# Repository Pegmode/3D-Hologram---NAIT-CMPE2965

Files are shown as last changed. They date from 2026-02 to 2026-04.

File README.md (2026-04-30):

# 3D Hologram Capstone Project - CMPE2965 NAIT
Capstone project for Computer Engineering Technology at the Northern Alberta Institute of Technology.<br>

by: Kaden Sparrow and [Daniel Chu](http://pegmode.github.io)<br>
course: CMPE2965-A02-1252

# Synopsis
This project is a rotating 3D volumetric display. Comprised of a rotating 16x32 LED display on a custom 6 layer circuit board with integrated microcontroller. Controlled via control UI running on windows. Able to load 3D models in the `.obj` format. 

<br>
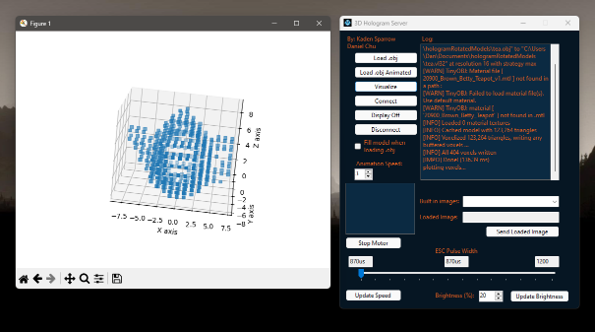
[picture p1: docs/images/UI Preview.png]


# Project History
This repo was initially worked on in a private repository created by Github classroom. As such all issues present in the original repository is not present in this one.

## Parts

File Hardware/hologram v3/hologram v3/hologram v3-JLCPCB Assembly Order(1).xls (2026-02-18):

JLCPCB BOM Tool - BOM Matching
BOM name：hologram v3-JLCPCB Assembly Order.xlsx |  |  | Download Time：2026-02-17 16:09:45 |  |  |  | * Our matching results are updated in real-time, but stock and prices may change. If it's been over 24 hours, please re-match before placing your order.
PCB Assembled Qty：5 |  |  | Est. Total Price：37.8607
Your BOM |  |  |  |  | Matched Parts |  |  |  |  |  |  | Order Information
Top Designator | Bottom Designator | Comment | Footprint | JLCPCB Part # | Matches | Part # | Manufacturer | Footprint | Description | Category | Warning | JLCPCB Part # | Product link | Lib Type | Qty | Source | Total Price ($)
 | C1,C2,C3,C4,C5,C6,C7,C8,C9,C10,C11,C12,C13,C14,C15,C16,C17,C18,C19,C20,C21,C22,C23,C24,C25,C26,C27,C28,C29,C30,C31,C32 | C_Small | Capacitor_SMD:C_0603_1608Metric |  | Select by Customer | CC0603KRX7R9BB104 | YAGEO | 0603 | 100nF 50V X7R ±10% 0603 Multilayer Ceramic Capacitors MLCC - SMD/SMT ROHS | Multilayer Ceramic Capacitors MLCC - SMD/SMT |  | C14663 | https://jlcpcb.com/partdetail/YAGEO-CC0603KRX7R9BB104/C14663 | Basic | 74 | 74 JLCPCB | 0.1924
C33 |  | 22u | Capacitor_SMD:C_1210 |  | Select by Customer | CS3225X7R226K250NRL | Samwha Capacitor | 1210 | 22uF 25V X7R ±10% 1210 Multilayer Ceramic Capacitors MLCC - SMD/SMT ROHS | Multilayer Ceramic Capacitors MLCC - SMD/SMT | 1.Multiple lines in the BOM have been matched to the same part. Please check if the matching is correct. ; | C2918511 | https://jlcpcb.com/partdetail/3220363-CS3225X7R226K250NRL/C2918511 | Extended | 26 | 26 JLCPCB | 2.262
C46,C47 | C53,C54,C61,C62,C63,C64 | 22u | Capacitor_SMD:C_1210_3225Metric |  | Select by Customer | CS3225X7R226K250NRL | Samwha Capacitor | 1210 | 22uF 25V X7R ±10% 1210 Multilayer Ceramic Capacitors MLCC - SMD/SMT ROHS | Multilayer Ceramic Capacitors MLCC - SMD/SMT | 1.The comment (CS3225X7R226K250NRL) of this part does not match the one (22u) provided in your BOM. Please confirm; 2.Multiple lines in the BOM have been matched to the same part. Please check if the matching is correct. ; | C2918511 | https://jlcpcb.com/partdetail/3220363-CS3225X7R226K250NRL/C2918511 | Extended | 26 | 26 JLCPCB | 2.262
C34,C37,C40,C42,C44 | C38,C39,C55,C56,C60 | 0.1u | Capacitor_SMD:C_0402_1005Metric |  | Select by Customer | CL05B104KB54PNC | Samsung Electro-Mechanics | 0402 | 100nF 50V X7R ±10% 0402 Multilayer Ceramic Capacitors MLCC - SMD/SMT ROHS | Multilayer Ceramic Capacitors MLCC - SMD/SMT | 1.The comment (CL05B104KB54PNC) of this part does not match the one (0.1u) provided in your BOM. Please confirm; | C307331 | https://jlcpcb.com/partdetail/291005-CL05B104KB54PNC/C307331 | Basic | 40 | 40 JLCPCB | 0.164
C35,C45 |  | 1u | Capacitor_SMD:C_0603_1608Metric |  | Select by Customer | 0603B105K250NT | FH (Guangdong Fenghua Advanced Tech) | 0603 | 1uF 25V X7R ±10% 0603 Multilayer Ceramic Capacitors MLCC - SMD/SMT ROHS | Multilayer Ceramic Capacitors MLCC - SMD/SMT | 1.The comment (0603B105K250NT) of this part does not match the one (1u) provided in your BOM. Please confirm; | C59302 | https://jlcpcb.com/partdetail/60350-0603B105K250NT/C59302 | Extended | 20 | 20 JLCPCB | 0.104
C36 |  | 10u | Capacitor_SMD:C_0805_2012Metric |  | Unconfirmed | GRM21BR61H106KE43L | Murata Electronics | 0805 | 10uF 50V X5R ±10% 0805 Multilayer Ceramic Capacitors MLCC - SMD/SMT ROHS | Multilayer Ceramic Capacitors MLCC - SMD/SMT | 1.The comment (GRM21BR61H106KE43L) of this part does not match the one (10u) provided in your BOM. Please confirm; | C440198 | https://jlcpcb.com/partdetail/439567-GRM21BR61H106KE43L/C440198 | Basic | 6 | 6 JLCPCB | 0.393
 | C48 | 100u | easyeda:CAP-SMD_BD6.3-L6.6-W6.6-LS7.3-FD |  | Select by System | MA25V100M6x6 | jieerrui | SMD,D6.3xL6mm | -55℃~+105℃ 100uF 2.65A@100kHz 2000hrs@105℃ 25V 30mΩ@100kHz 6.3mm 6mm Polymer ±20% SMD,D6.3xL6mm Polymer Aluminum Capacitors ROHS |  |  | C46550465 | https://jlcpcb.com/partdetail/jieerrui-MA25V100M6x6/C46550465 | Extended | 2 | 2 JLCPCB | 0.3258
C49,C50,C51,C52,C59,C65,C66,C67 |  | 47u | Capacitor_SMD:C_1210_3225Metric |  | Select by Customer | CS3225X7R476K160NRL | Samwha Capacitor | 1210 | 16V 47uF X7R ±10% 1210 Multilayer Ceramic Capacitors MLCC - SMD/SMT ROHS | Multilayer Ceramic Capacitors MLCC - SMD/SMT | 1.The comment (CS3225X7R476K160NRL) of this part does not match the one (47u) provided in your BOM. Please confirm; | C5440143 | https://jlcpcb.com/partdetail/6321105-CS3225X7R476K160NRL/C5440143 | Extended | 18 | 18 JLCPCB | 1.7784
C43 | C57 | 2.2u | Capacitor_SMD:C_0603_1608Metric |  | Select by Customer | GRM188Z71E225KE43D | Murata Electronics | 0603 | 2.2uF 25V X7R ±10% 0603 Multilayer Ceramic Capacitors MLCC - SMD/SMT ROHS | Multilayer Ceramic Capacitors MLCC - SMD/SMT | 1.The comment (GRM188Z71E225KE43D) of this part does not match the one (2.2u) provided in your BOM. Please confirm; | C415535 | https://jlcpcb.com/partdetail/408029-GRM188Z71E225KE43D/C415535 | Extended | 12 | 12 JLCPCB | 0.4836
D1 |  | 1N5819HW-7-F | easyeda:SOD-123_L2.7-W1.6-LS3.7-RD |  | Select by System | 1N5819HW-7-F | Diodes Incorporated | SOD-123 | -65℃~+150℃ 1 Independent 1A 1mA@40V 25A 40V 450mV@1A SOD-123 Schottky Diodes ROHS | Schottky Diodes |  | C82544 | https://jlcpcb.com/partdetail/DiodesIncorporated-1N5819HW_7F/C82544 | Extended | 15 | 15 JLCPCB | 0.4365
D2,D3,D4 |  | LESD5Z5.0CT1G | easyeda:SOD-523_L1.2-W0.8-LS1.6-BI |  | Select by System | LESD5Z5.0CT1G-HXY | HXY MOSFET | SOD-523 | -40℃~+125℃ 1 11.6V 15pF 1uA 5V 7.8V 90W@8/20us 9A Bidirectional ESD IEC 61000-4-2、IEC 61000-4-4 SOD-523 ESD and Surge Protection (TVS/ESD) ROHS | ESD And Surge Protection (TVS/ESD) |  | C5451650 | https://jlcpcb.com/partdetail/HXYMOSFET-LESD5Z5_0CT1GHXY/C5451650 | Extended | 20 | 20 JLCPCB | 0.254
 | D5,D6,D7,D8 | LESD5Z5.0CT1G | easyeda:SOD-523_L1.2-W0.8-LS1.6-BI |  | Select by System | LESD5Z5.0CT1G | LRC | SOD-523 | -40℃~+125℃ 18.6V 1uA 200W@8/20us 25pF 5V 7.8V 9.4A@8/20us Bidirectional IEC 61000-4-2、IEC 61000-4-4 TVS SOD-523 ESD and Surge Protection (TVS/ESD) ROHS | ESD And Surge Protection (TVS/ESD) |  | C136167 | https://jlcpcb.com/partdetail/LRC-LESD5Z50CT1G/C136167 | Extended | 20 | 20 JLCPCB | 0.342
 | D9 | SMBJ13A | easyeda:SMB_L4.6-W3.6-LS5.3-RD |  | Select by Customer | SMBJ13A | Littelfuse | DO-214AA | -65℃~+150℃ 14V 17.2V 1uA 23.2V 25.9A@10/1000us 600W@10/1000us IEC 61000-4-2 TVS Unidirectional DO-214AA ESD and Surge Protection (TVS/ESD) ROHS | ESD And Surge Protection (TVS/ESD) |  | C151252 | https://jlcpcb.com/partdetail/Littelfuse-SMBJ13A/C151252 | Extended | 5 | 5 JLCPCB | 0.546
 | D10 | KT-0603R | LED_SMD:LED_0603_1608Metric |  | Select by System | KT-0603R | Hubei KENTO Elec | 0603 | -40℃~+85℃ 120° 2.4V 20mA 300mcd 40mW 615nm~630nm 645nm Discrete Diode Red Water Clear 0603 LED Indication - Discrete ROHS | LED Indication - Discrete |  | C2286 | https://jlcpcb.com/partdetail/Hubei_KENTOElec-KT0603R/C2286 | Basic | 20 | 20 JLCPCB | 0.128
 | D11 | KT-0603Y | LED_SMD:LED_0603_1608Metric |  | Select by System | KT-0603Y | Hubei KENTO Elec | 0603 | -40℃~+85℃ 120° 175mcd 2.4V 40mW 584nm~594nm 596nm Discrete Diode Water Clear Yellow 0603 LED Indication - Discrete ROHS | LED Indication - Discrete |  | C2287 | https://jlcpcb.com/partdetail/Hubei_KENTOElec-KT0603Y/C2287 | Extended | 20 | 20 JLCPCB | 0.206
 | D12 | KT-0603B | LED_SMD:LED_0603_1608Metric |  | Select by System | KT-0603B | Hubei KENTO Elec | 0603 | 100mW 120° 175mcd 3.1V 460nm~475nm 469nm 5mA Blue Discrete Diode Water Clear 0603 LED Indication - Discrete ROHS | LED Indication - Discrete |  | C2288 | https://jlcpcb.com/partdetail/Hubei_KENTOElec-KT0603B/C2288 | Extended | 20 | 20 JLCPCB | 0.198
 | F1 | SMD1812-300C-30V | Fuse:Fuse_1812_4532Metric |  | Select by System | SMD1812-300C-30V | BNstar | 1812 | 10mΩ 30V 3A 4s 50A 60mΩ 6A 800mW 1812 Resettable Fuses ROHS | Resettable Fuses |  | C47002391 | https://jlcpcb.com/partdetail/BNstar-SMD1812_300C30V/C47002391 | Extended | 5 | 5 JLCPCB | 0.8335
L1 |  | 2.2u | easyeda:IND-SMD_L10.8-W10.0 |  | Select by Customer | CMLO1040H2R2MTT | Cybermax | SMD,10.8x10mm | 12A 2.2uH 5.8mΩ Magnetic Shielded Inductor ±20% SMD,10.8x10mm Power Inductors ROHS | Power Inductors | 1.The comment (CMLO1040H2R2MTT) of this part does not match the one (2.2u) provided in your BOM. Please confirm; | C439019 | https://jlcpcb.com/partdetail/Cybermax-CMLO1040H2R2MTT/C439019 | Extended | 2 | 2 JLCPCB | 0.5146
 | L2 | 4.7u | easyeda:IND-SMD_L10.8-W10.0 |  | Select by Customer | CMLO1040H4R7MTT | Cybermax | SMD,10.8x10mm | 12mΩ 4.7uH 8.5A Magnetic Shielded Inductor ±20% SMD,10.8x10mm Power Inductors ROHS | Power Inductors | 1.The comment (CMLO1040H4R7MTT) of this part does not match the one (4.7u) provided in your BOM. Please confirm; | C439021 | https://jlcpcb.com/partdetail/Cybermax-CMLO1040H4R7MTT/C439021 | Extended | 2 | 2 JLCPCB | 0.524
LED1,LED2,LED3,LED4,LED5,LED6,LED7,LED8,LED9,LED10,LED11,LED12,LED13,LED14,LED15,LED16,LED17,LED18,LED19,LED20,LED21,LED22,LED23,LED24,LED25,LED26,LED27,LED28,LED29,LED30,LED31,LED32,LED33,LED34,LED35,LED36,LED37,LED38,LED39,LED40,LED41,LED42,LED43,LED44,LED45,LED46,LED47,LED48,LED49,LED50,LED51,LED52,LED53,LED54,LED55,LED56,LED57,LED58,LED59,LED60,LED61,LED62,LED63,LED64,LED65,LED66,LED67,LED68,LED69,LED70,LED71,LED72,LED73,LED74,LED75,LED76,LED77,LED78,LED79,LED80,LED81,LED82,LED83,LED84,LED85,LED86,LED87,LED88,LED89,LED90,LED91,LED92,LED93,LED94,LED95,LED96,LED97,LED98,LED99,LED100,LED101,LED102,LED103,LED104,LED105,LED106,LED107,LED108,LED109,LED110,LED111,LED112,LED113,LED114,LED115,LED116,LED117,LED118,LED119,LED120,LED121,LED122,LED123,LED124,LED125,LED126,LED127,LED128,LED129,LED130,LED131,LED132,LED133,LED134,LED135,LED136,LED137,LED138,LED139,LED140,LED141,LED142,LED143,LED144,LED145,LED146,LED147,LED148,LED149,LED150,LED151,LED152,LED153,LED154,LED155,LED156,LED157,LED158,LED159,LED160,LED161,LED162,LED163,LED164,LED165,LED166,LED167,LED168,LED169,LED170,LED171,LED172,LED173,LED174,LED175,LED176,LED177,LED178,LED179,LED180,LED181,LED182,LED183,LED184,LED185,LED186,LED187,LED188,LED189,LED190,LED191,LED192,LED193,LED194,LED195,LED196,LED197,LED198,LED199,LED200,LED201,LED202,LED203,LED204,LED205,LED206,LED207,LED208,LED209,LED210,LED211,LED212,LED213,LED214,LED215,LED216,LED217,LED218 |  | 0805G(Green) | easyeda:LED0805-RD-flipped |  | Select by System | KT-0805G | Hubei KENTO Elec | 0805 | -40℃~+85℃ 100mW 120° 2.6V~3.1V 430mcd 513nm~528nm 525nm 5mA Discrete Diode Emerald Green Water Clear 0805 LED Indication - Discrete ROHS | LED Indication - Discrete |  | C2297 | https://jlcpcb.com/partdetail/Hubei_KENTOElec-KT0805G/C2297 | Basic | 0 | 0 JLCPCB | 0
LED219,LED220,LED221,LED222,LED223,LED224,LED225,LED226,LED227,LED228,LED229,LED230,LED231,LED232,LED233,LED234,LED235,LED236,LED237,LED238,LED239,LED240,LED241,LED242,LED243,LED244,LED245,LED246,LED247,LED248,LED249,LED250,LED251,LED252,LED253,LED254,LED255,LED256,LED257,LED258,LED259,LED260,LED261,LED262,LED263,LED264,LED265,LED266,LED267,LED268,LED269,LED270,LED271,LED272,LED273,LED274,LED275,LED276,LED277,LED278,LED279,LED280,LED281,LED282,LED283,LED284,LED285,LED286,LED287,LED288,LED289,LED290,LED291,LED292,LED293,LED294,LED295,LED296,LED297,LED298,LED299,LED300,LED301,LED302,LED303,LED304,LED305,LED306,LED307,LED308,LED309,LED310,LED311,LED312,LED313,LED314,LED315,LED316,LED317,LED318,LED319,LED320,LED321,LED322,LED323,LED324,LED325,LED326,LED327,LED328,LED329,LED330,LED331,LED332,LED333,LED334,LED335,LED336,LED337,LED338,LED339,LED340,LED341,LED342,LED343 |  | 0805G(Green) | easyeda:LED0805-RD-flipped |  | Select by System | KT-0805G | Hubei KENTO Elec | 0805 | -40℃~+85℃ 100mW 120° 2.6V~3.1V 430mcd 513nm~528nm 525nm 5mA Discrete Diode Emerald Green Water Clear 0805 LED Indication - Discrete ROHS | LED Indication - Discrete |  | C2297 | https://jlcpcb.com/partdetail/Hubei_KENTOElec-KT0805G/C2297 | Basic | 0 | 0 JLCPCB | 0
LED344,LED345,LED346,LED347,LED348,LED349,LED350,LED351,LED352,LED353,LED354,LED355,LED356,LED357,LED358,LED359,LED360,LED361,LED362,LED363,LED364,LED365,LED366,LED367,LED368,LED369,LED370,LED371,LED372,LED373,LED374,LED375,LED376,LED377,LED378,LED379,LED380,LED381,LED382,LED383,LED384,LED385,LED386,LED387,LED388,LED389,LED390,LED391,LED392,LED393,LED394,LED395,LED396,LED397,LED398,LED399,LED400,LED401,LED402,LED403,LED404,LED405,LED406,LED407,LED408,LED409,LED410,LED411,LED412,LED413,LED414,LED415,LED416,LED417,LED418,LED419,LED420,LED421,LED422,LED423,LED424,LED425,LED426,LED427,LED428,LED429,LED430,LED431,LED432,LED433,LED434,LED435,LED436,LED437,LED438,LED439,LED440,LED441,LED442,LED443,LED444,LED445,LED446,LED447,LED448,LED449,LED450,LED451,LED452,LED453,LED454,LED455,LED456,LED457,LED458,LED459,LED460,LED461,LED462,LED463,LED464,LED465,LED466,LED467,LED468,LED469,LED470,LED471,LED472,LED473,LED474,LED475,LED476,LED477,LED478,LED479,LED480,LED481,LED482,LED483,LED484,LED485,LED486,LED487,LED488,LED489,LED490,LED491,LED492,LED493,LED494,LED495,LED496,LED497,LED498,LED499,LED500,LED501,LED502,LED503,LED504,LED505,LED506,LED507,LED508,LED509,LED510,LED511,LED512 |  | 0805G(Green) | easyeda:LED0805-RD-flipped |  | Select by System | KT-0805G | Hubei KENTO Elec | 0805 | -40℃~+85℃ 100mW 120° 2.6V~3.1V 430mcd 513nm~528nm 525nm 5mA Discrete Diode Emerald Green Water Clear 0805 LED Indication - Discrete ROHS | LED Indication - Discrete |  | C2297 | https://jlcpcb.com/partdetail/Hubei_KENTOElec-KT0805G/C2297 | Basic | 0 | 0 JLCPCB | 0
 | R1 | 1.65k0.25% | Resistor_SMD:R_0603_1608Metric |  | Select by Customer | RT0603CRE071K65L | YAGEO | 0603 | -55℃~+155℃ 1.65kΩ 100mW 75V Thin Film Resistor ±0.25% ±50ppm/℃ 0603 Chip Resistor - Surface Mount ROHS | Chip Resistor - Surface Mount | 1.The comment (RT0603CRE071K65L) of this part does not match the one (1.65k0.25%) provided in your BOM. Please confirm; 2.Multiple lines in the BOM have been matched to the same part. Please check if the matching is correct. ; | C705912 | https://jlcpcb.com/partdetail/YAGEO-RT0603CRE071K65L/C705912 | Extended | 74 | 74 JLCPCB | 1.48
 | R2,R3,R4,R5,R6,R7,R8,R9,R10,R11,R12,R13,R14,R15,R16,R17,R18,R19,R20,R21,R22,R23,R24,R25,R26,R27,R28,R29,R30,R31,R32 | R_US | Resistor_SMD:R_0603_1608Metric |  | Select by Customer | RT0603CRE071K65L | YAGEO | 0603 | -55℃~+155℃ 1.65kΩ 100mW 75V Thin Film Resistor ±0.25% ±50ppm/℃ 0603 Chip Resistor - Surface Mount ROHS | Chip Resistor - Surface Mount | 1.Multiple lines in the BOM have been matched to the same part. Please check if the matching is correct. ; | C705912 | https://jlcpcb.com/partdetail/YAGEO-RT0603CRE071K65L/C705912 | Extended | 74 | 74 JLCPCB | 1.48
R33 |  | 1M | Resistor_SMD:R_0603_1608Metric |  | Unconfirmed | 0603WAF1004T5E | UNI-ROYAL(Uniroyal Elec) | 0603 | -55℃~+155℃ 100mW 1MΩ 75V Thick Film Resistor ±1% ±100ppm/℃ 0603 Chip Resistor - Surface Mount ROHS | Chip Resistor - Surface Mount | 1.The comment (0603WAF1004T5E) of this part does not match the one (1M) provided in your BOM. Please confirm; | C22935 | https://jlcpcb.com/partdetail/23662-0603WAF1004T5E/C22935 | Basic | 20 | 20 JLCPCB | 0.022
R34,R41,R47 | R62 | 10k | Resistor_SMD:R_0603_1608Metric |  | Select by Customer | FRH0603B1002TS | FOJAN | 0603 | -55℃~+155℃ 100mW 10kΩ 75V Thick Film Resistor ±0.1% ±100ppm/℃ 0603 Chip Resistor - Surface Mount ROHS | Chip Resistor - Surface Mount | 1.The comment (FRH0603B1002TS) of this part does not match the one (10k) provided in your BOM. Please confirm; | C5126214 | https://jlcpcb.com/partdetail/FOJAN-FRH0603B1002TS/C5126214 | Extended | 40 | 40 JLCPCB | 0.26
R35,R36 |  | 5.11k | Resistor_SMD:R_0603_1608Metric |  | Select by Customer | 0603WAF5101T5E | UNI-ROYAL(Uniroyal Elec) | 0603 | -55℃~+155℃ 100mW 5.1kΩ 75V Thick Film Resistor ±1% ±100ppm/℃ 0603 Chip Resistor - Surface Mount ROHS | Chip Resistor - Surface Mount | 1.The comment (0603WAF5101T5E) of this part does not match the one (5.11k) provided in your BOM. Please confirm; | C23186 | https://jlcpcb.com/partdetail/23913-0603WAF5101T5E/C23186 | Basic | 20 | 20 JLCPCB | 0.024
 | R37,R38,R39 | 2.2k | Resistor_SMD:R_0603_1608Metric |  | Select by Customer | 0603WAF2201T5E | UNI-ROYAL(Uniroyal Elec) | 0603 | -55℃~+155℃ 100mW 2.2kΩ 75V Thick Film Resistor ±1% ±100ppm/℃ 0603 Chip Resistor - Surface Mount ROHS | Chip Resistor - Surface Mount | 1.The comment (0603WAF2201T5E) of this part does not match the one (2.2k) provided in your BOM. Please confirm; | C4190 | https://jlcpcb.com/partdetail/4597-0603WAF2201T5E/C4190 | Basic | 20 | 20 JLCPCB | 0.026
R42,R43,R44,R45,R46,R49,R50,R55,R65,R66 |  | 33 | Resistor_SMD:R_0402_1005Metric |  | Select by Customer | 0603WAF330JT5E | UNI-ROYAL(Uniroyal Elec) | 0603 | -55℃~+155℃ 100mW 33Ω 75V Thick Film Resistor ±1% ±100ppm/℃ 0603 Chip Resistor - Surface Mount ROHS | Chip Resistor - Surface Mount | 1.The comment (0603WAF330JT5E) of this part does not match the one (33) provided in your BOM. Please confirm; | C23140 | https://jlcpcb.com/partdetail/23867-0603WAF330JT5E/C23140 | Basic | 30 | 30 JLCPCB | 0.036
R48 |  | 75k | Resistor_SMD:R_0603_1608Metric |  | Select by Customer | RT0603BRD0775KL | YAGEO | 0603 | -55℃~+155℃ 100mW 75V 75kΩ Thin Film Resistor ±0.1% ±25ppm/℃ 0603 Chip Resistor - Surface Mount ROHS | Chip Resistor - Surface Mount | 1.The comment (RT0603BRD0775KL) of this part does not match the one (75k) provided in your BOM. Please confirm; | C723587 | https://jlcpcb.com/partdetail/YAGEO-RT0603BRD0775KL/C723587 | Extended | 20 | 20 JLCPCB | 0.536
R51 |  | 13k | Resistor_SMD:R_0603_1608Metric |  | Select by Customer | TC0325B1302T5F | UNI-ROYAL(Uniroyal Elec) | 0603 | -55℃~+155℃ 100mW 13kΩ Thin Film Resistor ±0.1% ±25ppm/℃ 0603 Chip Resistor - Surface Mount ROHS |  | 1.The comment (TC0325B1302T5F) of this part does not match the one (13k) provided in your BOM. Please confirm; | C50670543 | https://jlcpcb.com/partdetail/53304658-TC0325B1302T5F/C50670543 | Extended | 2 | 2 JLCPCB | 0.0212
R52,R53 | R40,R58 | 100k | Resistor_SMD:R_0603_1608Metric |  | Select by Customer | 0603WAF1003T5E | UNI-ROYAL(Uniroyal Elec) | 0603 | -55℃~+155℃ 100kΩ 100mW 75V Thick Film Resistor ±1% ±100ppm/℃ 0603 Chip Resistor - Surface Mount ROHS | Chip Resistor - Surface Mount | 1.The comment (0603WAF1003T5E) of this part does not match the one (100k) provided in your BOM. Please confirm; | C25803 | https://jlcpcb.com/partdetail/26546-0603WAF1003T5E/C25803 | Basic | 40 | 40 JLCPCB | 0.044
 | R57 | 1.5k | Resistor_SMD:R_0603_1608Metric |  | Select by System | 0603WAF1501T5E | UNI-ROYAL(Uniroyal Elec) | 0603 | -55℃~+155℃ 1.5kΩ 100mW 75V Thick Film Resistor ±1% ±100ppm/℃ 0603 Chip Resistor - Surface Mount ROHS | Chip Resistor - Surface Mount |  | C22843 | https://jlcpcb.com/partdetail/23570-0603WAF1501T5E/C22843 | Basic | 20 | 20 JLCPCB | 0.024
 | R59 | 1.2k | Resistor_SMD:R_0603_1608Metric |  | Select by System | 0603WAF1201T5E | UNI-ROYAL(Uniroyal Elec) | 0603 | -55℃~+155℃ 1.2kΩ 100mW 75V Thick Film Resistor ±1% ±100ppm/℃ 0603 Chip Resistor - Surface Mount ROHS | Chip Resistor - Surface Mount |  | C22765 | https://jlcpcb.com/partdetail/23492-0603WAF1201T5E/C22765 | Basic | 20 | 20 JLCPCB | 0.026
 | R60 | 330 | Resistor_SMD:R_0603_1608Metric |  | Select by System | 0603WAF3300T5E | UNI-ROYAL(Uniroyal Elec) | 0603 | -55℃~+155℃ 100mW 330Ω 75V Thick Film Resistor ±1% ±100ppm/℃ 0603 Chip Resistor - Surface Mount ROHS | Chip Resistor - Surface Mount |  | C23138 | https://jlcpcb.com/partdetail/23865-0603WAF3300T5E/C23138 | Basic | 20 | 20 JLCPCB | 0.026
R54 | R63,R64 | 47k | Resistor_SMD:R_0603_1608Metric |  | Unconfirmed | 0603WAF4702T5E | UNI-ROYAL(Uniroyal Elec) | 0603 | -55℃~+155℃ 100mW 47kΩ 75V Thick Film Resistor ±1% ±100ppm/℃ 0603 Chip Resistor - Surface Mount ROHS | Chip Resistor - Surface Mount | 1.The comment (0603WAF4702T5E) of this part does not match the one (47k) provided in your BOM. Please confirm; | C25819 | https://jlcpcb.com/partdetail/26562-0603WAF4702T5E/C25819 | Basic | 40 | 40 JLCPCB | 0.048
 | SW1 | SW_Reset | easyeda:KEY-SMD_L4.0-W3.0-LS4.9-1 |  | Select by Customer | HX 3x4x2-2P-1.6N TACTILE SWITCH | hanxia | SMD,4x3mm | 1.6N 100,000 cycles 12V 2mm 3mm 4mm 50mA Black No Round Button SMD(SMT) Tab SPST Surface Mount,Vertical Without Bracket SMD,4x3mm Tactile Switches ROHS |  | 1.Multiple lines in the BOM have been matched to the same part. Please check if the matching is correct. ; | C49234124 | https://jlcpcb.com/partdetail/C49234124 | Extended | 10 | 10 JLCPCB | 0.2
 | SW2 | SW_Boot | easyeda:KEY-SMD_L4.0-W3.0-LS4.9-1 |  | Select by Customer | HX 3x4x2-2P-1.6N TACTILE SWITCH | hanxia | SMD,4x3mm | 1.6N 100,000 cycles 12V 2mm 3mm 4mm 50mA Black No Round Button SMD(SMT) Tab SPST Surface Mount,Vertical Without Bracket SMD,4x3mm Tactile Switches ROHS |  | 1.Multiple lines in the BOM have been matched to the same part. Please check if the matching is correct. ; | C49234124 | https://jlcpcb.com/partdetail/C49234124 | Extended | 10 | 10 JLCPCB | 0.2
 | SW3 | SW_OPT1 | easyeda:KEY-SMD_L4.0-W3.0-LS4.9-1 |  | Select by Customer | HX 3x4x2-2P-1.6N TACTILE SWITCH | hanxia | SMD,4x3mm | 1.6N 100,000 cycles 12V 2mm 3mm 4mm 50mA Black No Round Button SMD(SMT) Tab SPST Surface Mount,Vertical Without Bracket SMD,4x3mm Tactile Switches ROHS |  | 1.Multiple lines in the BOM have been matched to the same part. Please check if the matching is correct. ; | C49234124 | https://jlcpcb.com/partdetail/C49234124 | Extended | 10 | 10 JLCPCB | 0.2
 | SW4 | SW_OPT2 | easyeda:KEY-SMD_L4.0-W3.0-LS4.9-1 |  | Select by Customer | HX 3x4x2-2P-1.6N TACTILE SWITCH | hanxia | SMD,4x3mm | 1.6N 100,000 cycles 12V 2mm 3mm 4mm 50mA Black No Round Button SMD(SMT) Tab SPST Surface Mount,Vertical Without Bracket SMD,4x3mm Tactile Switches ROHS |  | 1.Multiple lines in the BOM have been matched to the same part. Please check if the matching is correct. ; | C49234124 | https://jlcpcb.com/partdetail/C49234124 | Extended | 10 | 10 JLCPCB | 0.2
 | U1,U2,U3,U4,U5,U6,U7,U8,U9,U10,U11,U12,U13,U14,U15,U16,U17,U18,U19,U20,U21,U22,U23,U24,U25,U26,U27,U28,U29,U30,U31,U32 | SM16106SC | easyeda:QSOP-24_L8.7-W4.0-P0.64-LS6.0-BL |  | Select by System | SM16206S | Shenzhen Sunmoon Micro | QSOP-24 | -40℃~+85℃ 16 2.5% 25MHz 3.3V~5V 32mA QSOP-24 LED Drivers ROHS | LED Drivers |  | C121618 | https://jlcpcb.com/partdetail/Shenzhen_SunmoonMicro-SM16206S/C121618 | Extended | 64 | 64 JLCPCB | 4.7936
U33 |  | ESP32-S3-WROOM-1(N16R8) | easyeda:WIRELM-SMD_ESP32-S3-WROOM-1 |  | Select by System | ESP32-S3-WROOM-1-N16R8 | Espressif Systems | SMD,25.5x18mm | -103.5dBm -40℃~+65℃ 2.4GHz 20.5dBm 355mA 3V~3.6V 95mA ESP32-S3R8 On-board PCB Antenna UART、SPI、I2C、GPIO、I2S、USB SMD,25.5x18mm WiFi Modules ROHS | WiFi Modules |  | C2913202 | https://jlcpcb.com/partdetail/3198300-ESP32_S3_WROOM_1N16R8/C2913202 | Extended | 2 | 2 JLCPCB | 11.3824
U34 |  | SY8286ARAC12v->4v | easyeda:QFN-20_L3.0-W3.0-P0.45-BL-EP1.0 |  | Unconfirmed | SY8286ARAC | Silergy Corp | QFN-20-EP(3x3) | -40℃~+85℃@(TA) 1 120uA 4V~23V 510kHz~690kHz 6A Adjustable Buck Buck Built-in Yes QFN-20-EP(3x3) DC-DC Converters ROHS | DC-DC Converters | 1.Multiple lines in the BOM have been matched to the same part. Please check if the matching is correct. ; | C178251 | https://jlcpcb.com/partdetail/SilergyCorp-SY8286ARAC/C178251 | Extended | 4 | 4 JLCPCB | 2.3448
 | U36 | SY8286ARAC12v->3.3v | easyeda:QFN-20_L3.0-W3.0-P0.45-BL-EP1.0 |  | Unconfirmed | SY8286ARAC | Silergy Corp | QFN-20-EP(3x3) | -40℃~+85℃@(TA) 1 120uA 4V~23V 510kHz~690kHz 6A Adjustable Buck Buck Built-in Yes QFN-20-EP(3x3) DC-DC Converters ROHS | DC-DC Converters | 1.Multiple lines in the BOM have been matched to the same part. Please check if the matching is correct. ; | C178251 | https://jlcpcb.com/partdetail/SilergyCorp-SY8286ARAC/C178251 | Extended | 4 | 4 JLCPCB | 2.3448
U35 |  | ~ | easyeda:USB-C-SMD_TYPE-C-6PIN-2MD-073 |  | Select by System | TYPE-C 16PIN 2MD(073) | SHOU HAN | SMD | -25℃~+85℃ 1 16P 3A 5,000 times 5V Black Female Surface Mount, Right Angle Type-C SMD USB Connectors ROHS | USB Connectors |  | C2765186 | https://jlcpcb.com/partdetail/SHOUHAN-TYPE_C_16PIN_2MD_073/C2765186 | Extended | 3 | 3 JLCPCB | 0.1941
 | R61 | 45k | Resistor_SMD:R_0603_1608Metric |  | Unconfirmed | CR164502F | Meritek | 0603 | -55℃~+155℃ 100mW 45kΩ Thick Film Resistor ±1% ±100ppm/℃ 0603 Chip Resistor - Surface Mount ROHS | Chip Resistor - Surface Mount | 1.The comment (CR164502F) of this part does not match the one (45k) provided in your BOM. Please confirm; | C4013975 | https://jlcpcb.com/partdetail/Meritek-CR164502F/C4013975 | Extended | 20 | 0 JLCPCB | 0
J1 |  | Conn_01x06 | Connector_PinHeader_2.54mm:PinHeader_1x06_P2.54mm_Vertical |  | No matches | No Part Selected
 | J2 | Conn_01x06_Socket | TerminalBlock:TerminalBlock_MaiXu_MX126-5.0-06P_1x06_P5.00mm |  | No matches | No Part Selected
TP1 |  | TEST_USB5V | TestPoint:TestPoint_Pad_3.0x3.0mm |  | No matches | No Part Selected
 |  |  |  |  |  |  |  |  |  |  |  |  |  |  |  |  |  | top | bottom | comment | footprint | part detail | qty | source | lib | cost
 |  |  |  |  |  |  |  |  |  |  |  |  |  |  |  |  |  |  | C1,C2,C3,C4,C5,C6,C7,C8,C9,C10,C11,C12,C13,C14,C15,C16,C17,C18,C19,C20,C21,C22,C23,C24,C25,C26,C27,C28,C29,C30,C31,C32 | C_Small | Capacitor_SMD:C_0603_1608Metric | CC0603KRX7R9BB104 | 74 | JLCPCB | Basic | C$0.2614
 |  |  |  |  |  |  |  |  |  |  |  |  |  |  |  |  |  |  |  |  |  | C14663
 |  |  |  |  |  |  |  |  |  |  |  |  |  |  |  |  |  |  |  |  |  | 100nF 50V X7R ±10% 0603 Multilayer Ceramic Capacitors MLCC - SMD/SMT ROHS
 |  |  |  |  |  |  |  |  |  |  |  |  |  |  |  |  |  | C33 |  | 22u | Capacitor_SMD:C_0805_2012Metric | CL21A226MAQNNNE | 20 | JLCPCB | Basic | C$0.7174
 |  |  |  |  |  |  |  |  |  |  |  |  |  |  |  |  |  |  |  |  |  | C45783
 |  |  |  |  |  |  |  |  |  |  |  |  |  |  |  |  |  |  |  |  |  | 22uF 25V X5R ±20% 0805 Multilayer Ceramic Capacitors MLCC - SMD/SMT ROHS
 |  |  |  |  |  |  |  |  |  |  |  |  |  |  |  |  |  | C34,C37,C40,C42,C44 | C38,C39,C55,C56,C60 | 0.1u | Capacitor_SMD:C_0402_1005Metric | CL05B104KB54PNC | 40 | JLCPCB | Basic | C$0.2228
 |  |  |  |  |  |  |  |  |  |  |  |  |  |  |  |  |  |  |  |  |  | C307331
 |  |  |  |  |  |  |  |  |  |  |  |  |  |  |  |  |  |  |  |  |  | 100nF 50V X7R ±10% 0402 Multilayer Ceramic Capacitors MLCC - SMD/SMT ROHS
 |  |  |  |  |  |  |  |  |  |  |  |  |  |  |  |  |  | C35,C45 |  | 1u | Capacitor_SMD:C_0603_1608Metric | 0603B105K250NT | 20 | JLCPCB | Extended | C$0.1413
 |  |  |  |  |  |  |  |  |  |  |  |  |  |  |  |  |  |  |  |  |  | C59302
 |  |  |  |  |  |  |  |  |  |  |  |  |  |  |  |  |  |  |  |  |  | 1uF 25V X7R ±10% 0603 Multilayer Ceramic Capacitors MLCC - SMD/SMT ROHS
 |  |  |  |  |  |  |  |  |  |  |  |  |  |  |  |  |  | C36 |  | 10u | Capacitor_SMD:C_0805_2012Metric | GRM21BR61H106KE43L | 6 | JLCPCB | Basic | C$0.5340
 |  |  |  |  |  |  |  |  |  |  |  |  |  |  |  |  |  |  |  |  |  | C440198
 |  |  |  |  |  |  |  |  |  |  |  |  |  |  |  |  |  |  |  |  |  | 10uF 50V X5R ±10% 0805 Multilayer Ceramic Capacitors MLCC - SMD/SMT ROHS
 |  |  |  |  |  |  |  |  |  |  |  |  |  |  |  |  |  | C46,C47 | C53,C54,C61,C62,C63,C64 | 22u | Capacitor_SMD:C_1210_3225Metric | CS3225X7R226K250NRL | 24 | JLCPCB | Extended | C$2.8370
 |  |  |  |  |  |  |  |  |  |  |  |  |  |  |  |  |  |  |  |  |  | C2918511
 |  |  |  |  |  |  |  |  |  |  |  |  |  |  |  |  |  |  |  |  |  | 22uF 25V X7R ±10% 1210 Multilayer Ceramic Capacitors MLCC - SMD/SMT ROHS
 |  |  |  |  |  |  |  |  |  |  |  |  |  |  |  |  |  |  | C48 | 100u | easyeda:CAP-SMD_BD6.3-L6.6-W6.6-LS7.3-FD | MA25V100M6x6 | 2 | JLCPCB | Extended | C$0.4427
 |  |  |  |  |  |  |  |  |  |  |  |  |  |  |  |  |  |  |  |  |  | C46550465
 |  |  |  |  |  |  |  |  |  |  |  |  |  |  |  |  |  |  |  |  |  | -55℃~+105℃ 100uF 2.65A@100kHz 2000hrs@105℃ 25V 30mΩ@100kHz 6.3mm 6mm Polymer ±20% SMD,D6.3xL6mm Polymer Aluminum Capacitors ROHS
 |  |  |  |  |  |  |  |  |  |  |  |  |  |  |  |  |  | C49,C50,C51,C52,C59,C65,C66,C67 |  | 47u | Capacitor_SMD:C_1210_3225Metric | CS3225X7R476K160NRL | 18 | JLCPCB | Extended | C$2.4163
 |  |  |  |  |  |  |  |  |  |  |  |  |  |  |  |  |  |  |  |  |  | C5440143
 |  |  |  |  |  |  |  |  |  |  |  |  |  |  |  |  |  |  |  |  |  | 16V 47uF X7R ±10% 1210 Multilayer Ceramic Capacitors MLCC - SMD/SMT ROHS
 |  |  |  |  |  |  |  |  |  |  |  |  |  |  |  |  |  | C43 | C57 | 2.2u | Capacitor_SMD:C_0603_1608Metric | GRM188Z71E225KE43D | 12 | JLCPCB | Extended | C$0.6571
 |  |  |  |  |  |  |  |  |  |  |  |  |  |  |  |  |  |  |  |  |  | C415535
 |  |  |  |  |  |  |  |  |  |  |  |  |  |  |  |  |  |  |  |  |  | 2.2uF 25V X7R ±10% 0603 Multilayer Ceramic Capacitors MLCC - SMD/SMT ROHS
 |  |  |  |  |  |  |  |  |  |  |  |  |  |  |  |  |  | D1 |  | 1N5819HW-7-F | easyeda:SOD-123_L2.7-W1.6-LS3.7-RD | 1N5819HW-7-F | 15 | JLCPCB | Extended | C$0.5931
 |  |  |  |  |  |  |  |  |  |  |  |  |  |  |  |  |  |  |  |  |  | C82544
 |  |  |  |  |  |  |  |  |  |  |  |  |  |  |  |  |  |  |  |  |  | -65℃~+150℃ 1 Independent 1A 1mA@40V 25A 40V 450mV@1A SOD-123 Schottky Diodes ROHS
 |  |  |  |  |  |  |  |  |  |  |  |  |  |  |  |  |  | D2,D3,D4 |  | LESD5Z5.0CT1G | easyeda:SOD-523_L1.2-W0.8-LS1.6-BI | LESD5Z5.0CT1G-HXY | 20 | JLCPCB | Extended | C$0.3451
 |  |  |  |  |  |  |  |  |  |  |  |  |  |  |  |  |  |  |  |  |  | C5451650
 |  |  |  |  |  |  |  |  |  |  |  |  |  |  |  |  |  |  |  |  |  | -40℃~+125℃ 1 11.6V 15pF 1uA 5V 7.8V 90W@8/20us 9A Bidirectional ESD IEC 61000-4-2、IEC 61000-4-4 SOD-523 ESD and Surge Protection (TVS/ESD) ROHS
 |  |  |  |  |  |  |  |  |  |  |  |  |  |  |  |  |  |  | D5,D6,D7,D8 | LESD5Z5.0CT1G | easyeda:SOD-523_L1.2-W0.8-LS1.6-BI | LESD5Z5.0CT1G | 20 | JLCPCB | Extended | C$0.4647
 |  |  |  |  |  |  |  |  |  |  |  |  |  |  |  |  |  |  |  |  |  | C136167
 |  |  |  |  |  |  |  |  |  |  |  |  |  |  |  |  |  |  |  |  |  | -40℃~+125℃ 18.6V 1uA 200W@8/20us 25pF 5V 7.8V 9.4A@8/20us Bidirectional IEC 61000-4-2、IEC 61000-4-4 TVS SOD-523 ESD and Surge Protection (TVS/ESD) ROHS
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

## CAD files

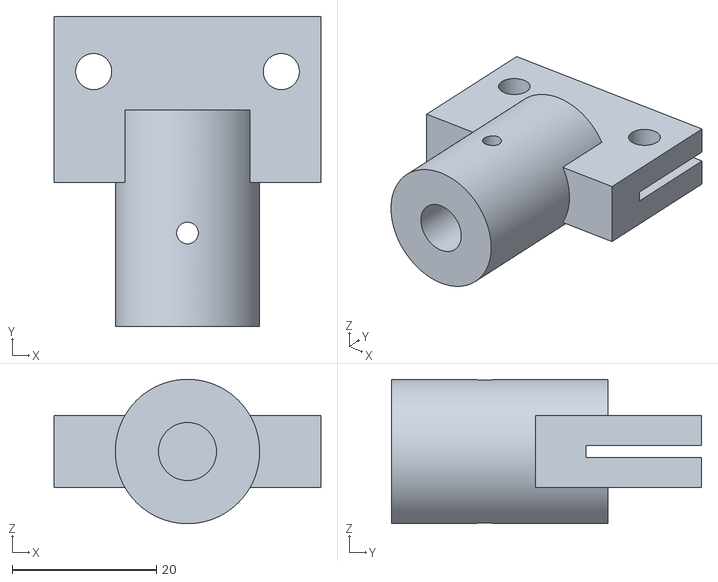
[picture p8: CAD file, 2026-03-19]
Hardware/Mechanical Parts/Board Connector Bottom/BoardConnectorBottom V5.stl
37.0 x 43.0 x 20.0

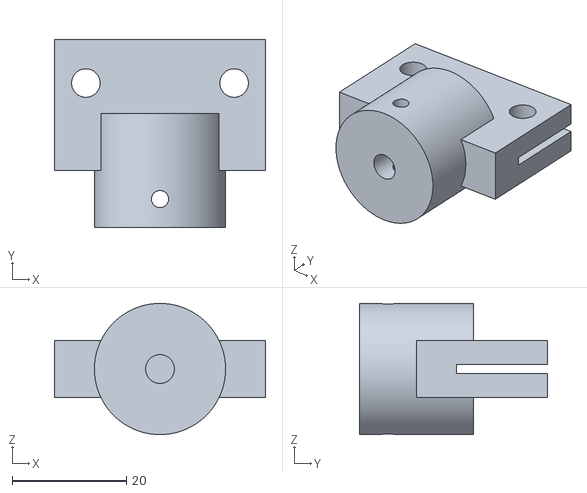
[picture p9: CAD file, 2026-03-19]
Hardware/Mechanical Parts/Board Connector Top/BoardConnectorTop V2.stl
37.0 x 33.0 x 23.0

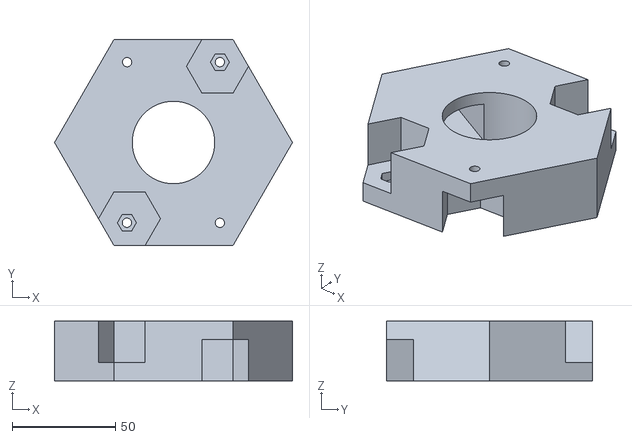
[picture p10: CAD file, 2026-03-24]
Hardware/Mechanical Parts/Motor Coupler Spacer/Motor Coupler Spacer V4.stl
115.5 x 100.0 x 29.0

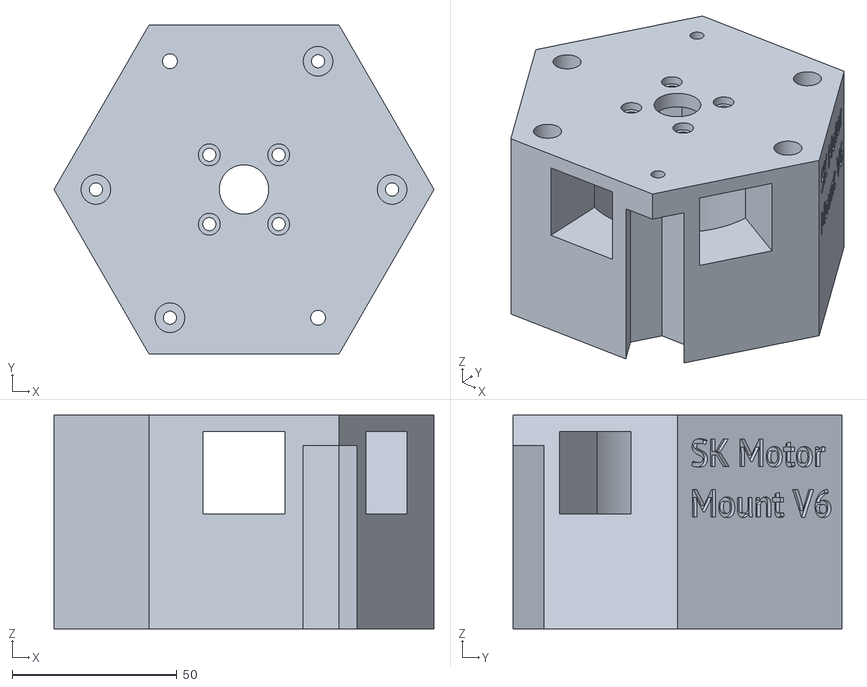
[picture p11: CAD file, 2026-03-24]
Hardware/Mechanical Parts/Motor Mount/SK Motor Mount V6.stl
115.5 x 100.0 x 65.0

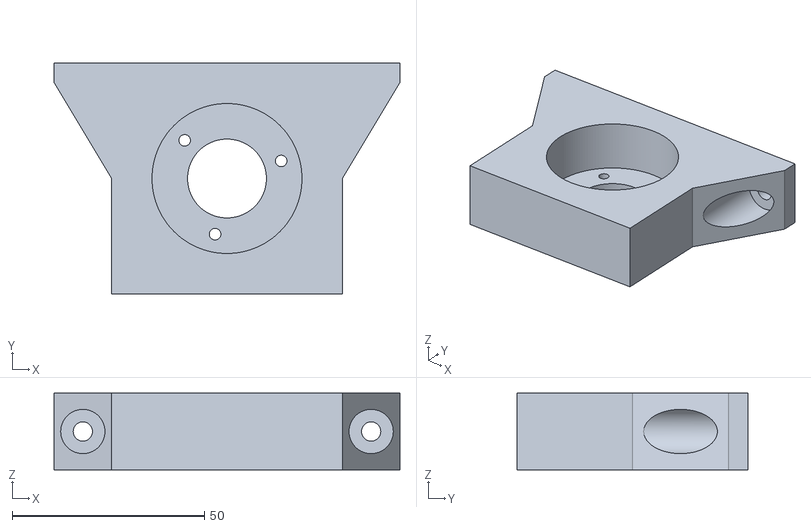
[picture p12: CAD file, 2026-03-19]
Hardware/Mechanical Parts/Rotary Encoder Mount/Rotary Encoder Mount V3.stl
90.0 x 60.0 x 20.0

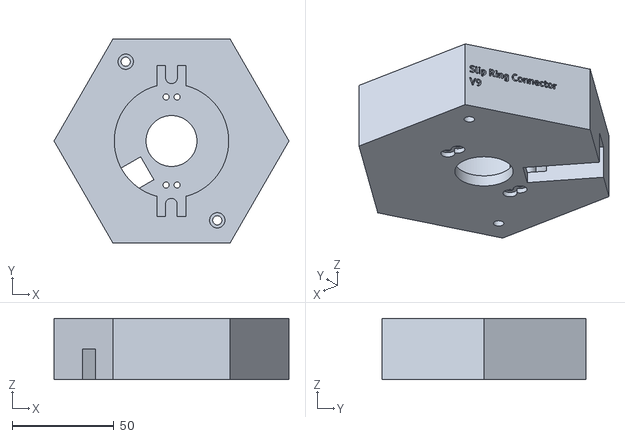
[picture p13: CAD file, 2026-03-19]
Hardware/Mechanical Parts/Slip Ring Connector/Slip Ring Connector V9.stl
115.5 x 100.0 x 30.0

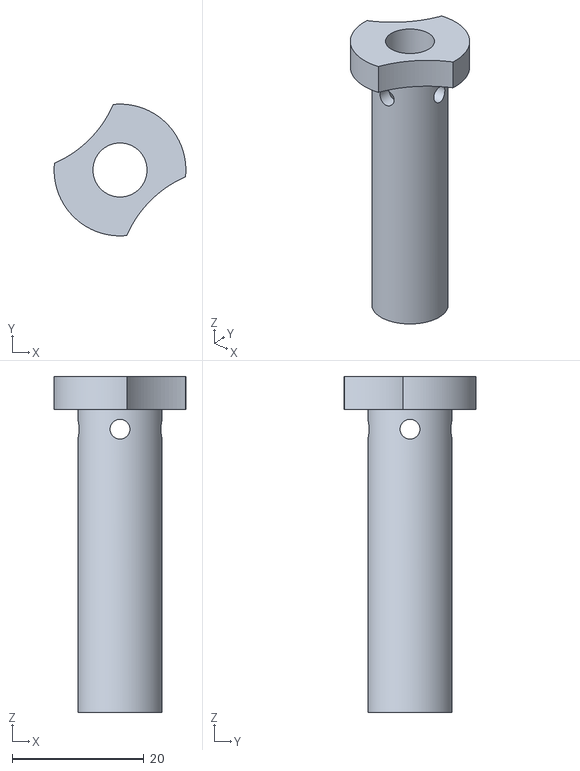
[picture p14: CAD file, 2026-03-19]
Hardware/Mechanical Parts/Slip Ring Shaft Adapter/Slip Ring Shaft Adapter V4.stl
20.0 x 20.0 x 51.0

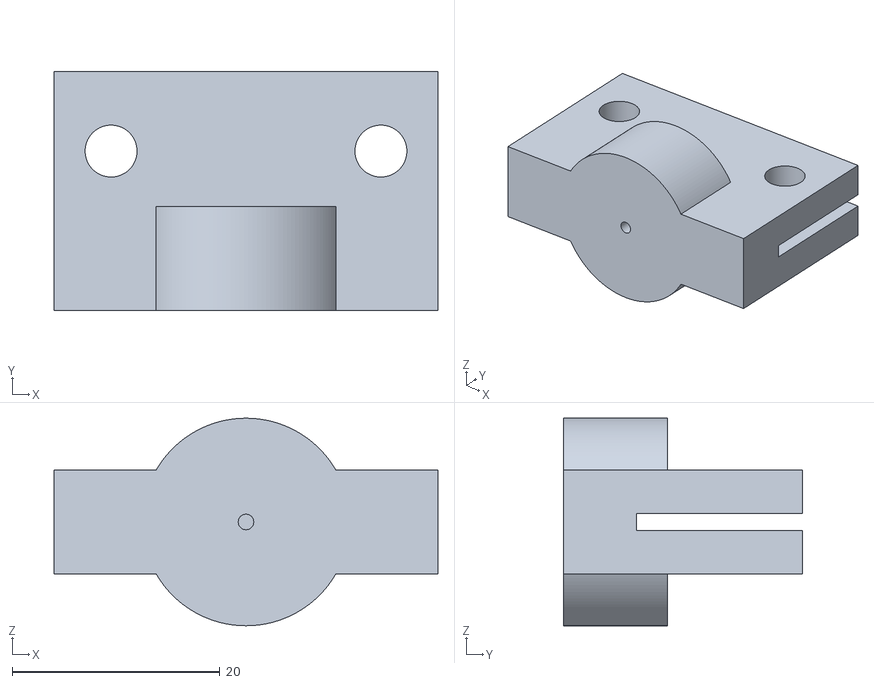
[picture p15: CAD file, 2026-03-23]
Hardware/Mechanical Parts/Test Parts/BoardConnectorBallancer V2.stl
37.0 x 23.0 x 20.0

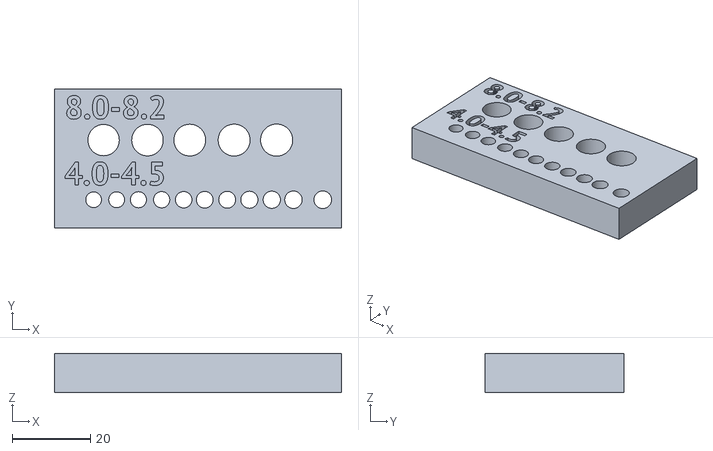
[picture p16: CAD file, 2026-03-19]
Hardware/Mechanical Parts/Test Parts/Fit Sizing Tester.stl
73.3 x 35.4 x 10.0

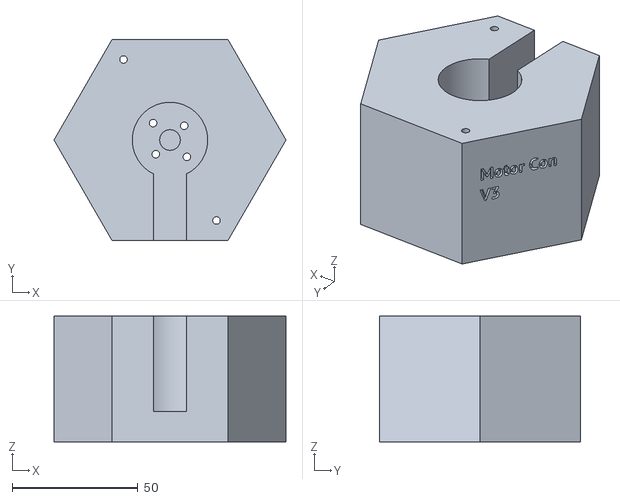
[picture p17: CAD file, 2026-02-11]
Hardware/Mechanical Parts/Motor Mount/Motor connector V3.stl
92.4 x 80.0 x 50.0

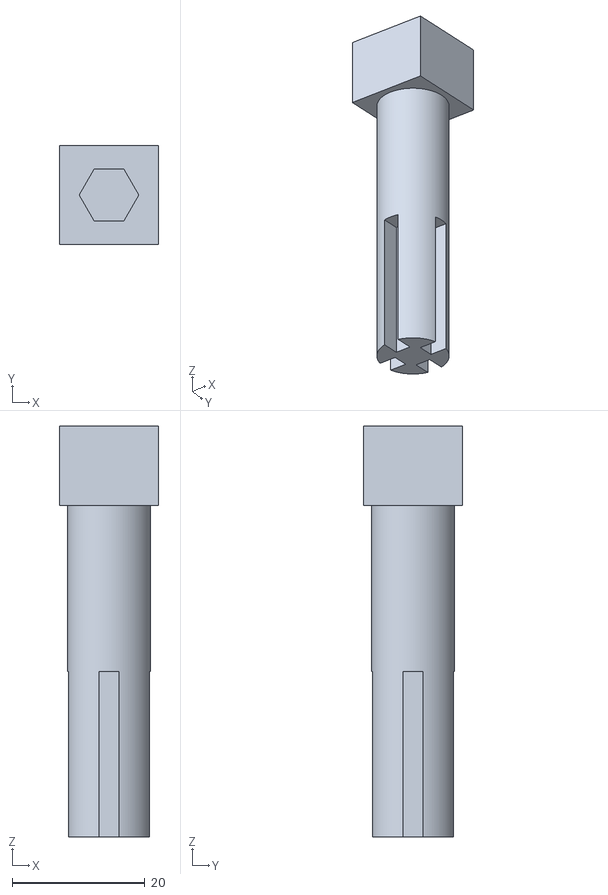
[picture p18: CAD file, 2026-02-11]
Hardware/Mechanical Parts/Test Parts/Test Shaft Bolt Adapter/Test Shaft Bolt Adapter.stl
15.0 x 15.0 x 62.0

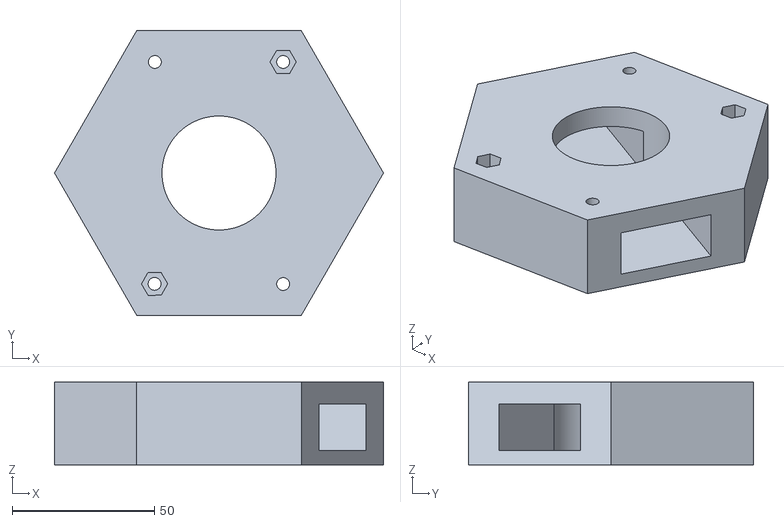
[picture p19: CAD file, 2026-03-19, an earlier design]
Hardware/Mechanical Parts/Motor Coupler Spacer/Motor Coupler Spacer V3.stl
115.5 x 100.0 x 29.0

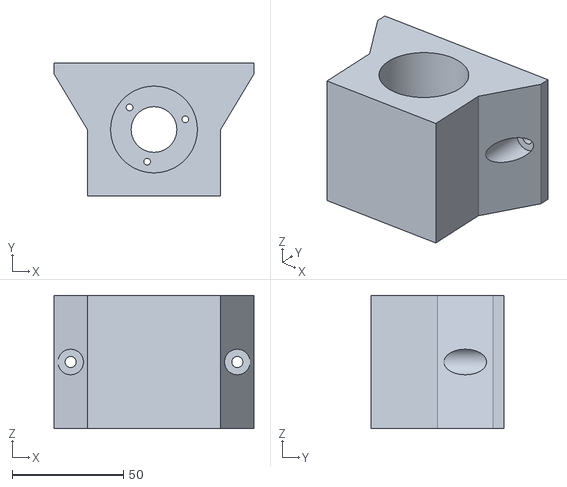
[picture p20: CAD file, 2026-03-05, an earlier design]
Hardware/Mechanical Parts/Rotary Encoder Mount/Rotary Encoder Mount V1.stl
90.0 x 60.0 x 60.0

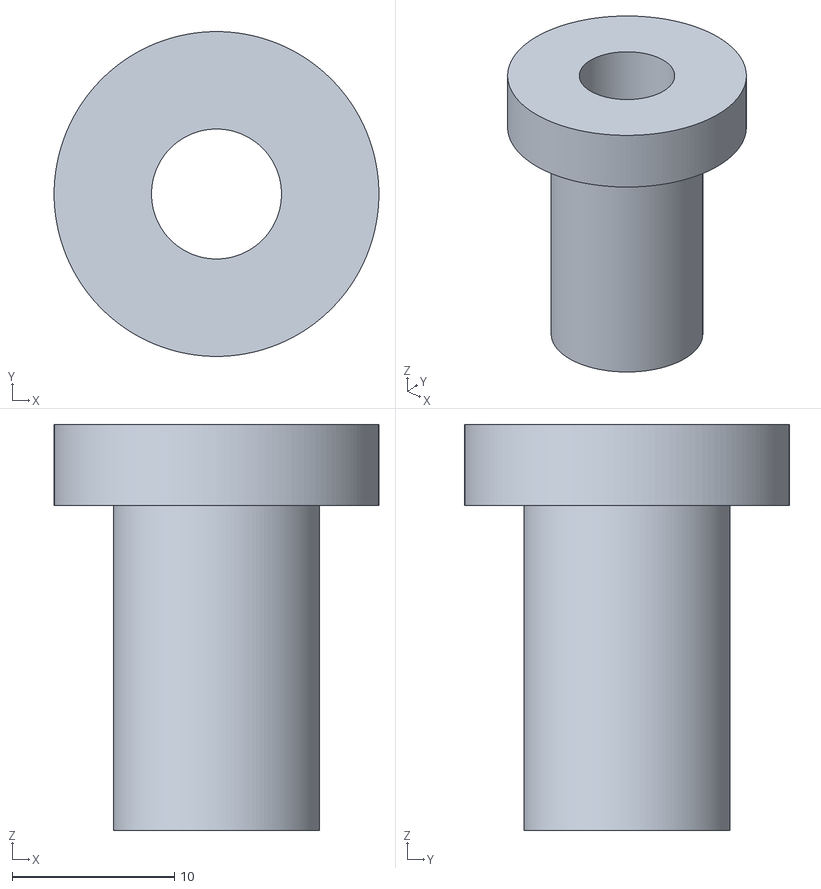
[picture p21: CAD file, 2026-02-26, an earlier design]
Hardware/Mechanical Parts/Slip Ring Shaft Adapter/Slip Ring Shaft Adapter.stl
20.0 x 20.0 x 25.0

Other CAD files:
Hardware/Mechanical Parts/Motor Mount/SK Motor Connector V5.stl
Hardware/Mechanical Parts/Motor Mount/SK Morot Mount V3.stl
Hardware/Mechanical Parts/Slip Ring Connector/Slip Ring Connector V6.stl
Hardware/Mechanical Parts/Test Parts/BoardConnectorBallancer.stl
Hardware/Mechanical Parts/Motor Mount/Motor connector V1.stl
Hardware/Mechanical Parts/Motor Mount/Motor connector V2.stl
Hardware/Mechanical Parts/Motor Mount/SK Motor Mount V1.stl
Hardware/Mechanical Parts/Motor Mount/SK Motor Mount V2.stl
Hardware/Mechanical Parts/Slip Ring Connector/Slip Ring Connector V1.stl
Hardware/Mechanical Parts/Slip Ring Connector/Slip Ring Connector V2.stl
Hardware/Mechanical Parts/Slip Ring Connector/Slip Ring Connector V4.stl

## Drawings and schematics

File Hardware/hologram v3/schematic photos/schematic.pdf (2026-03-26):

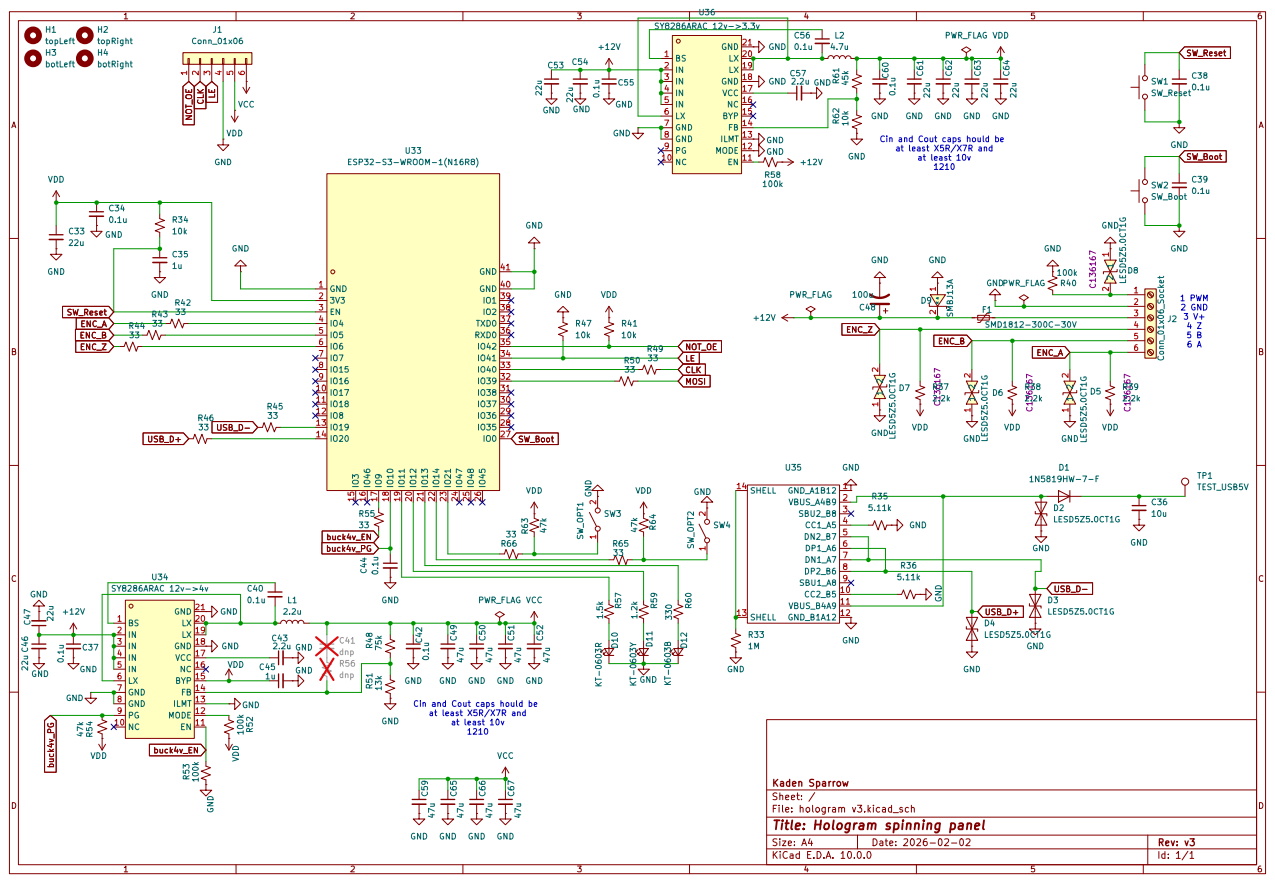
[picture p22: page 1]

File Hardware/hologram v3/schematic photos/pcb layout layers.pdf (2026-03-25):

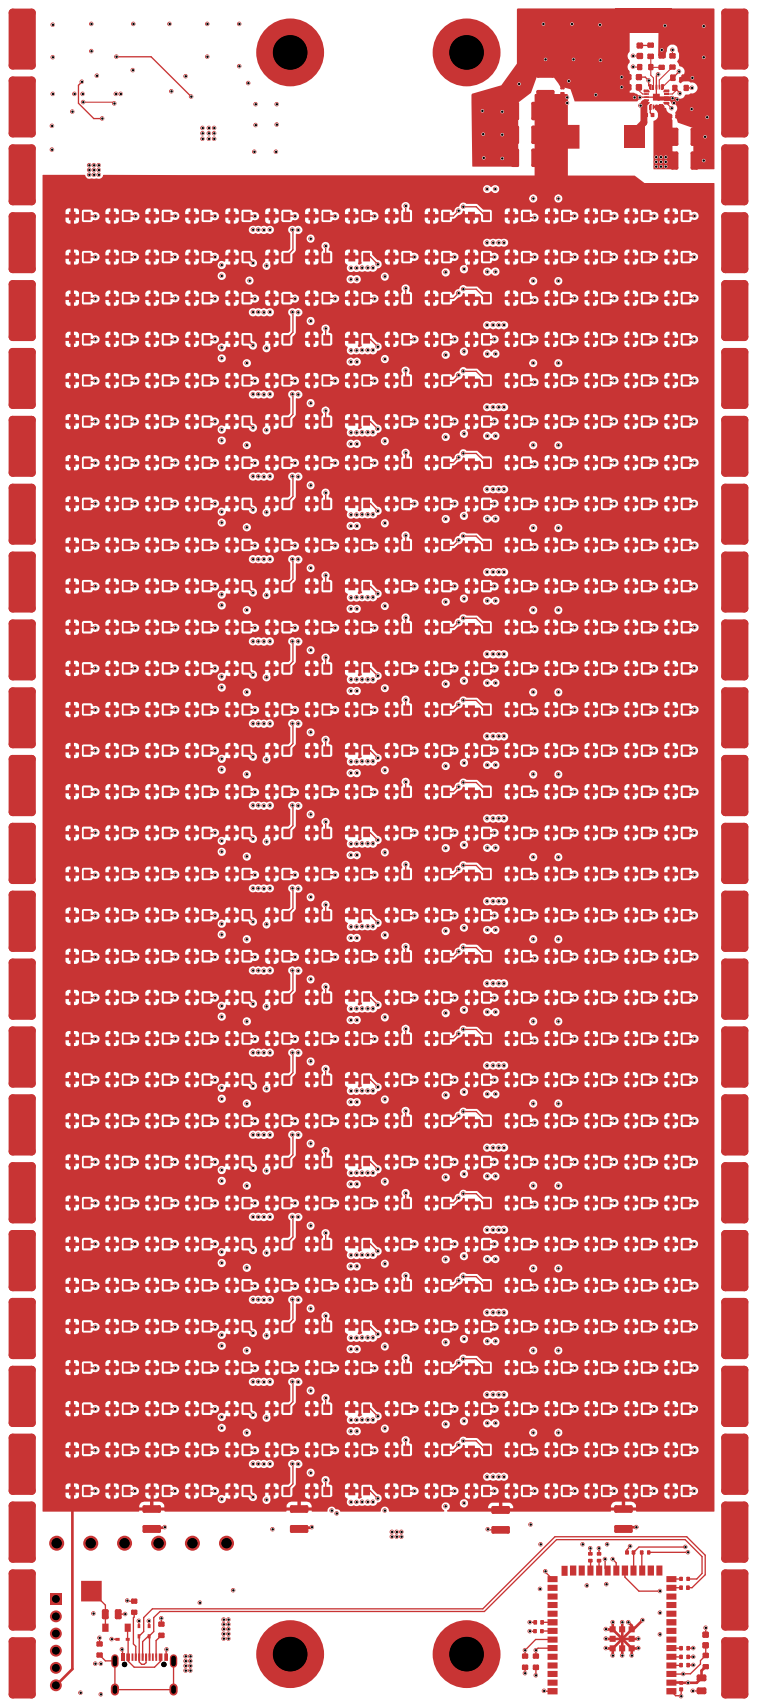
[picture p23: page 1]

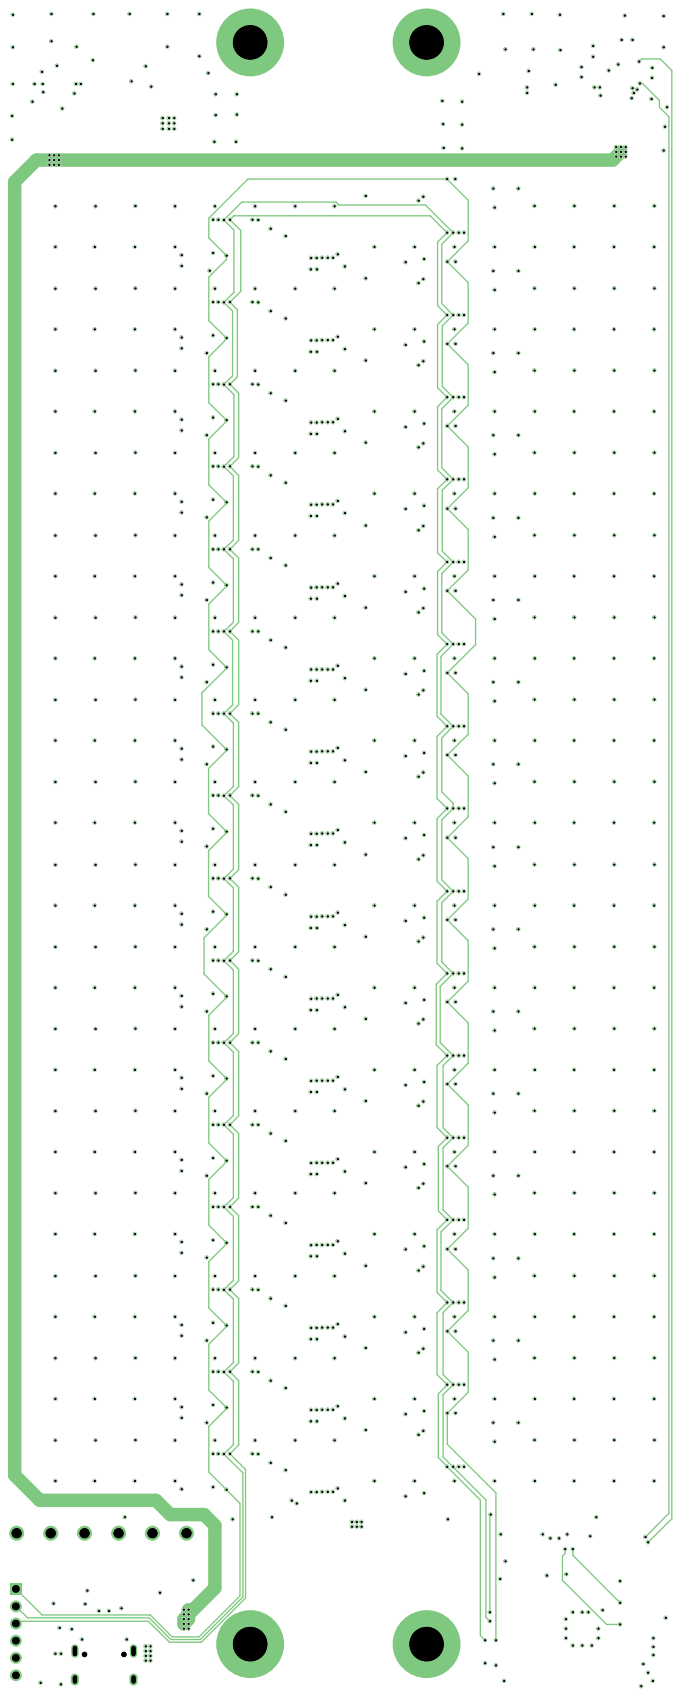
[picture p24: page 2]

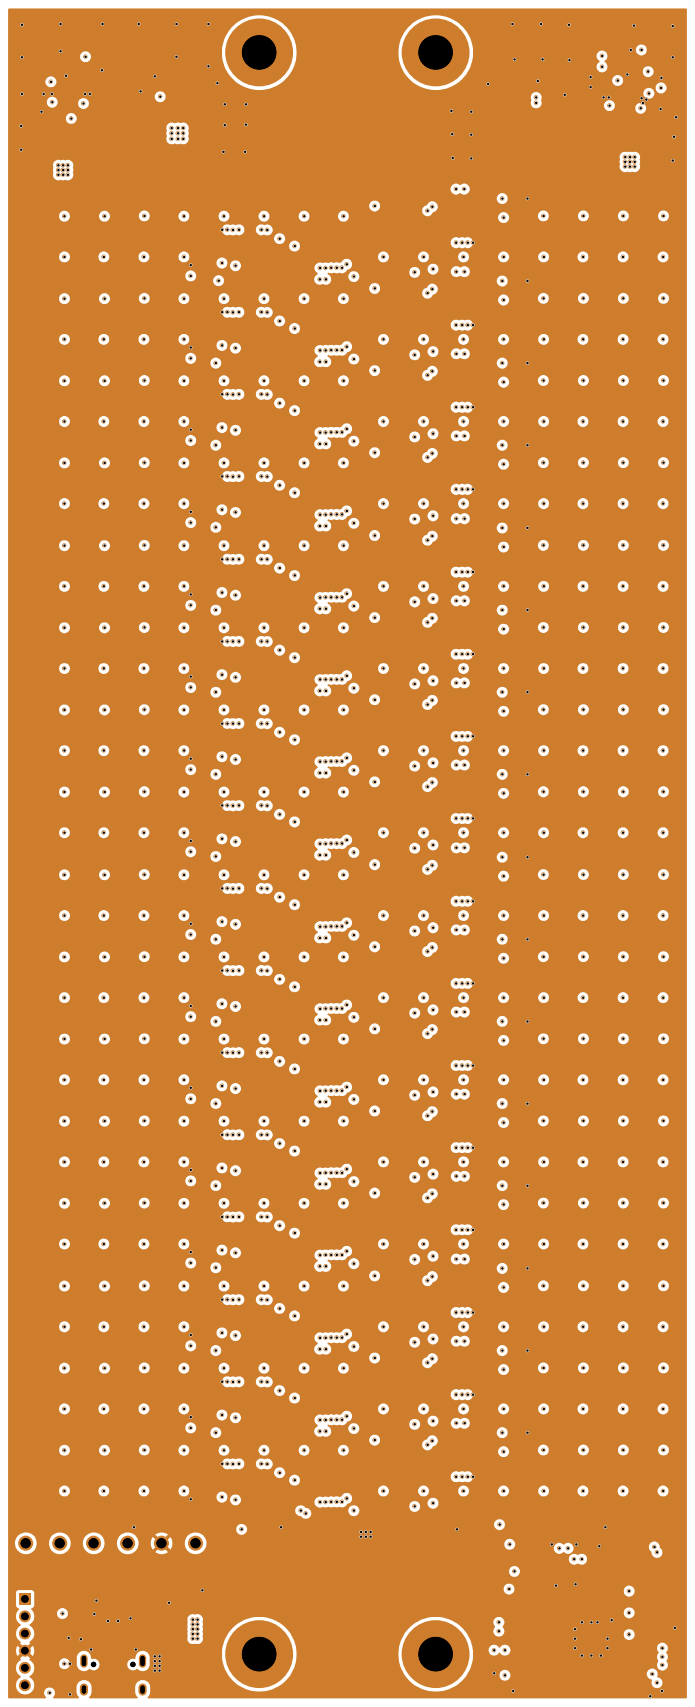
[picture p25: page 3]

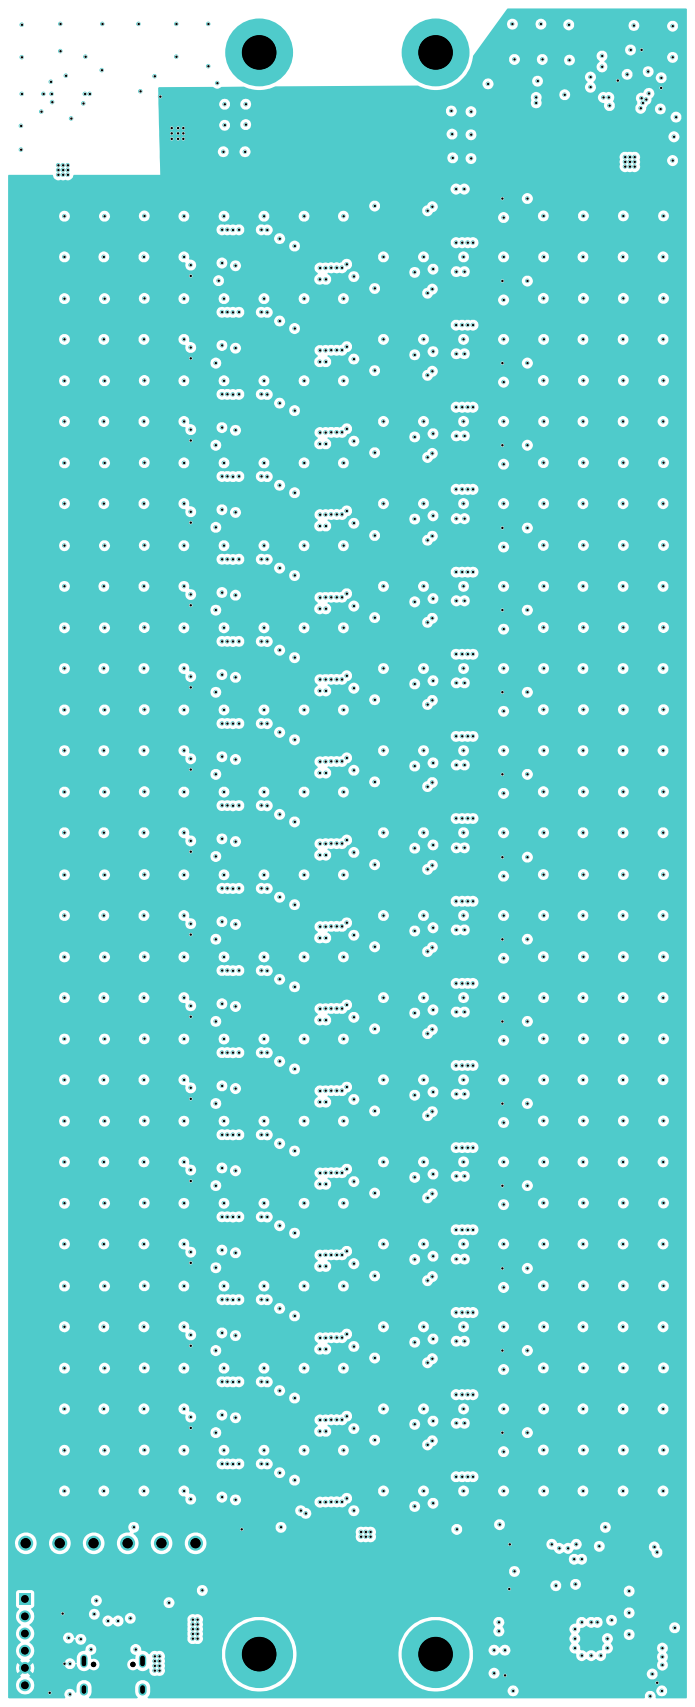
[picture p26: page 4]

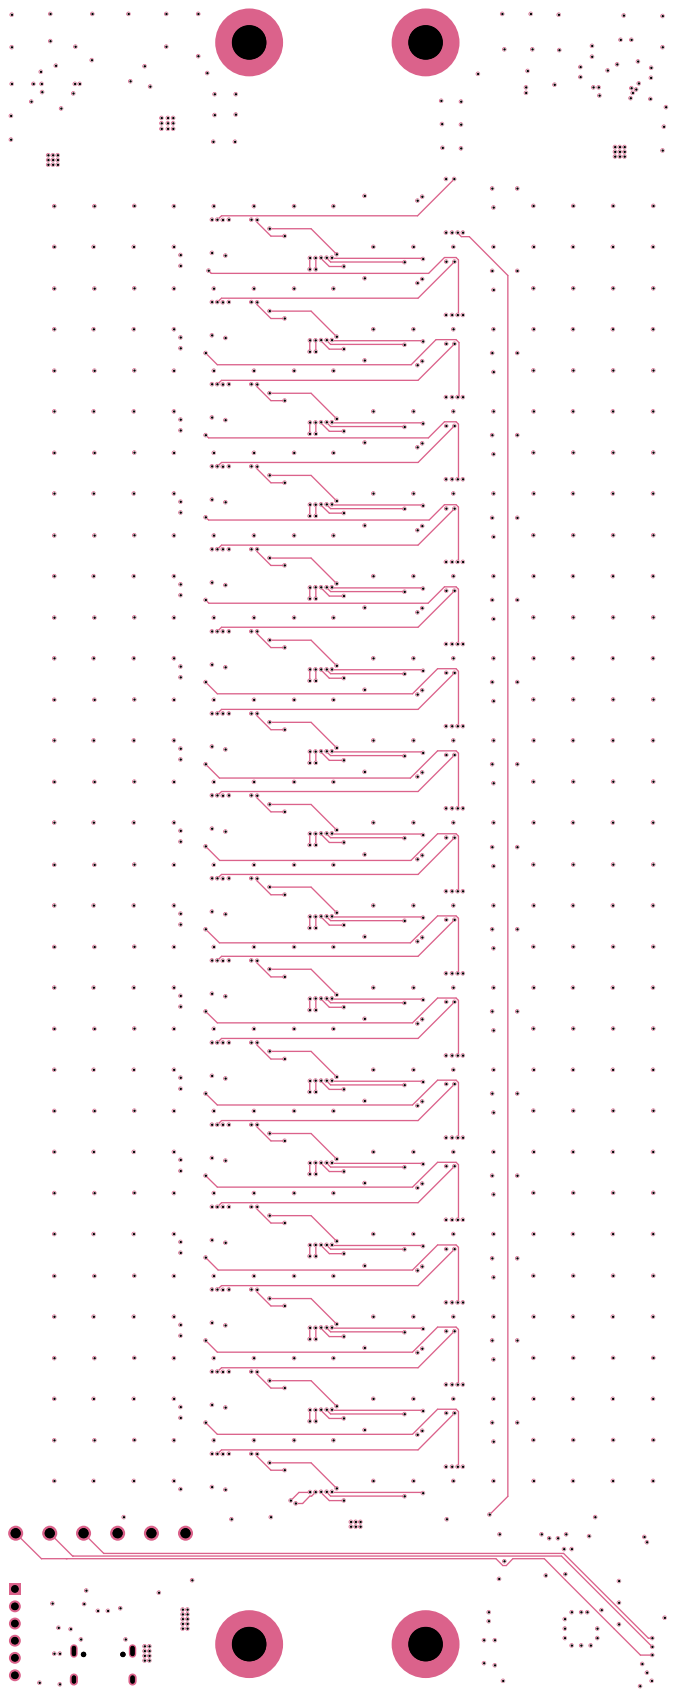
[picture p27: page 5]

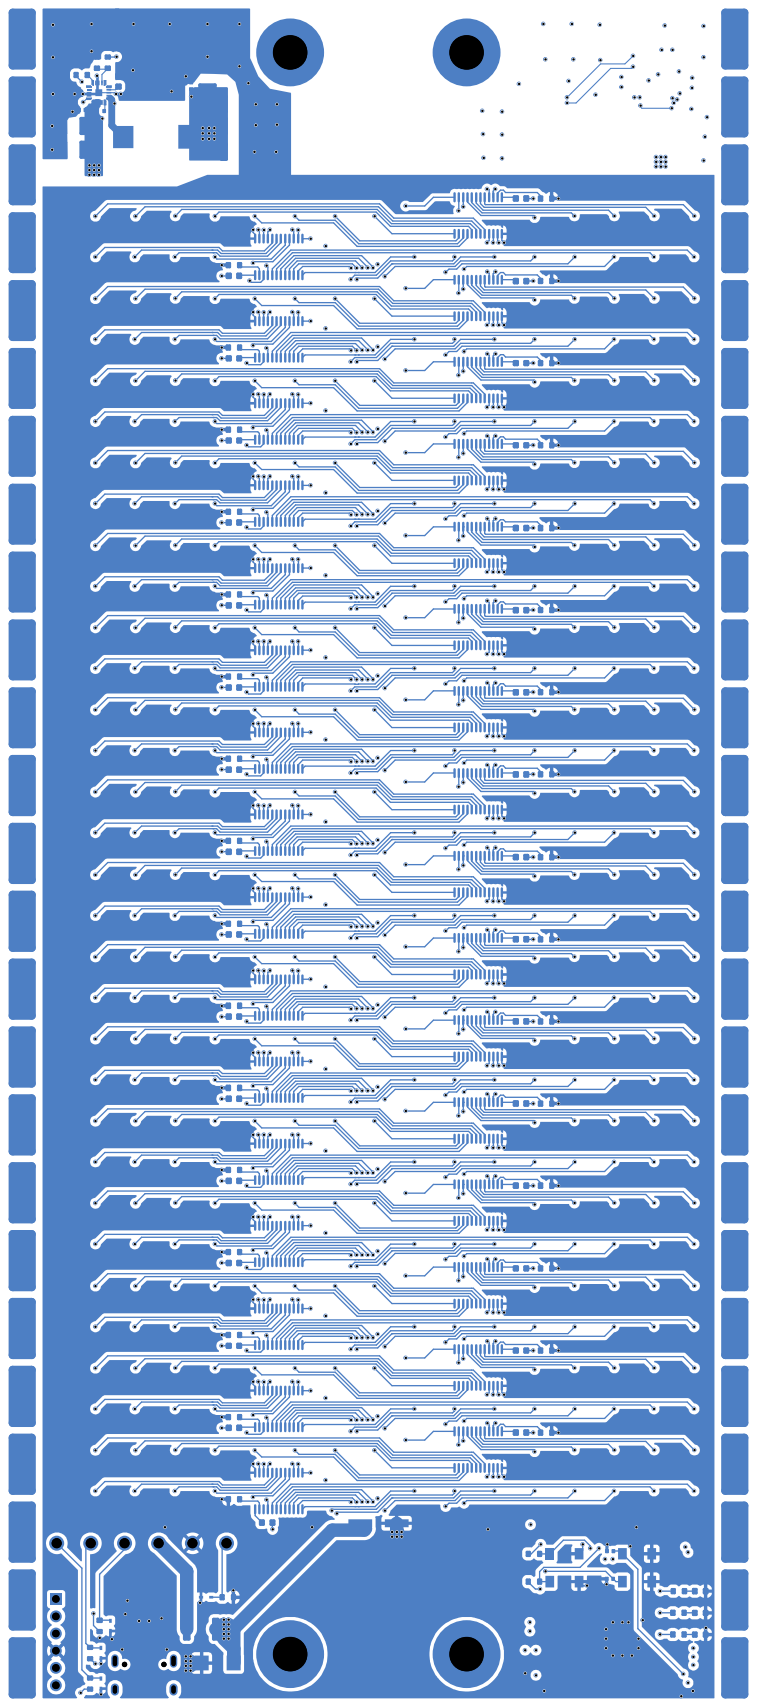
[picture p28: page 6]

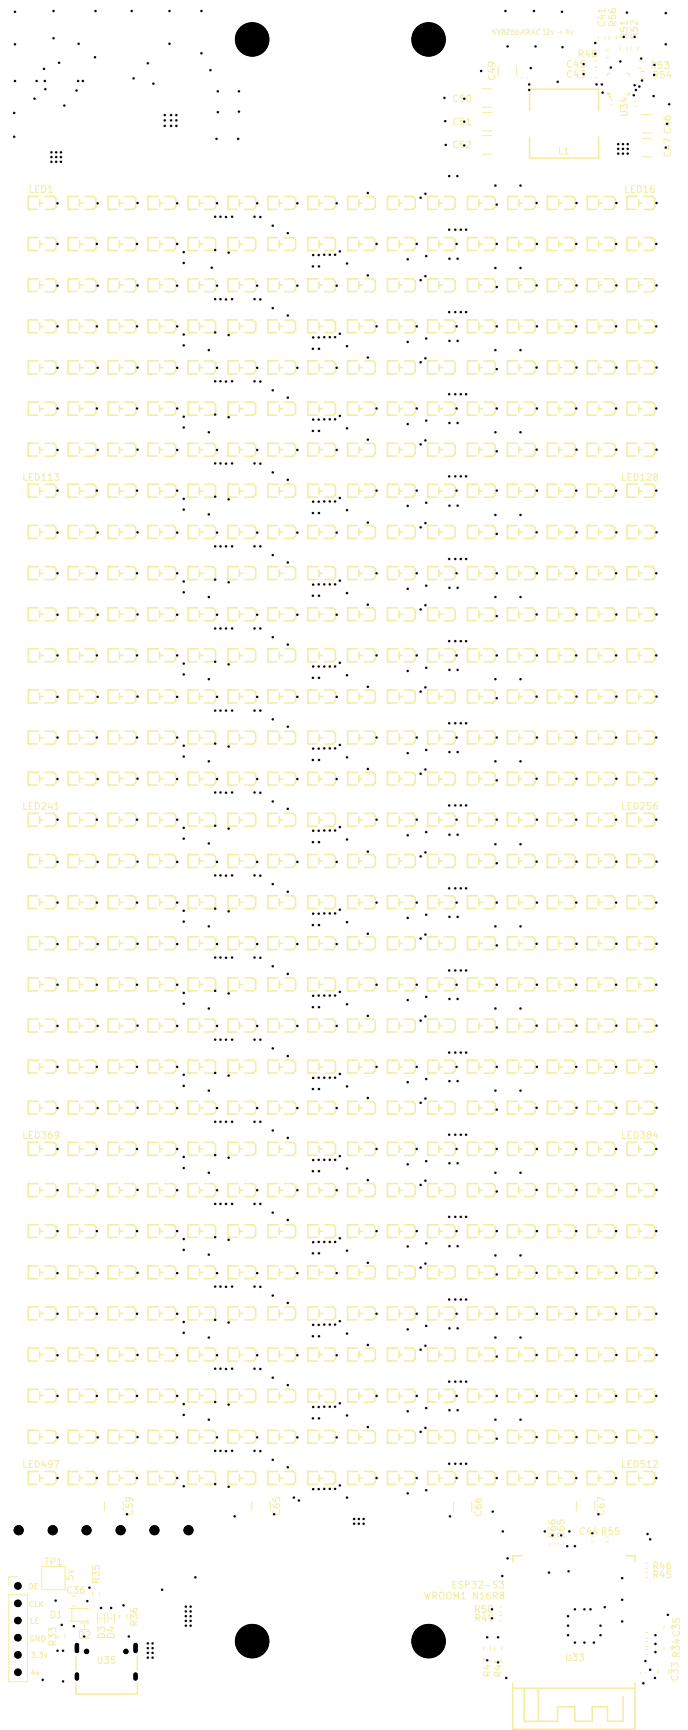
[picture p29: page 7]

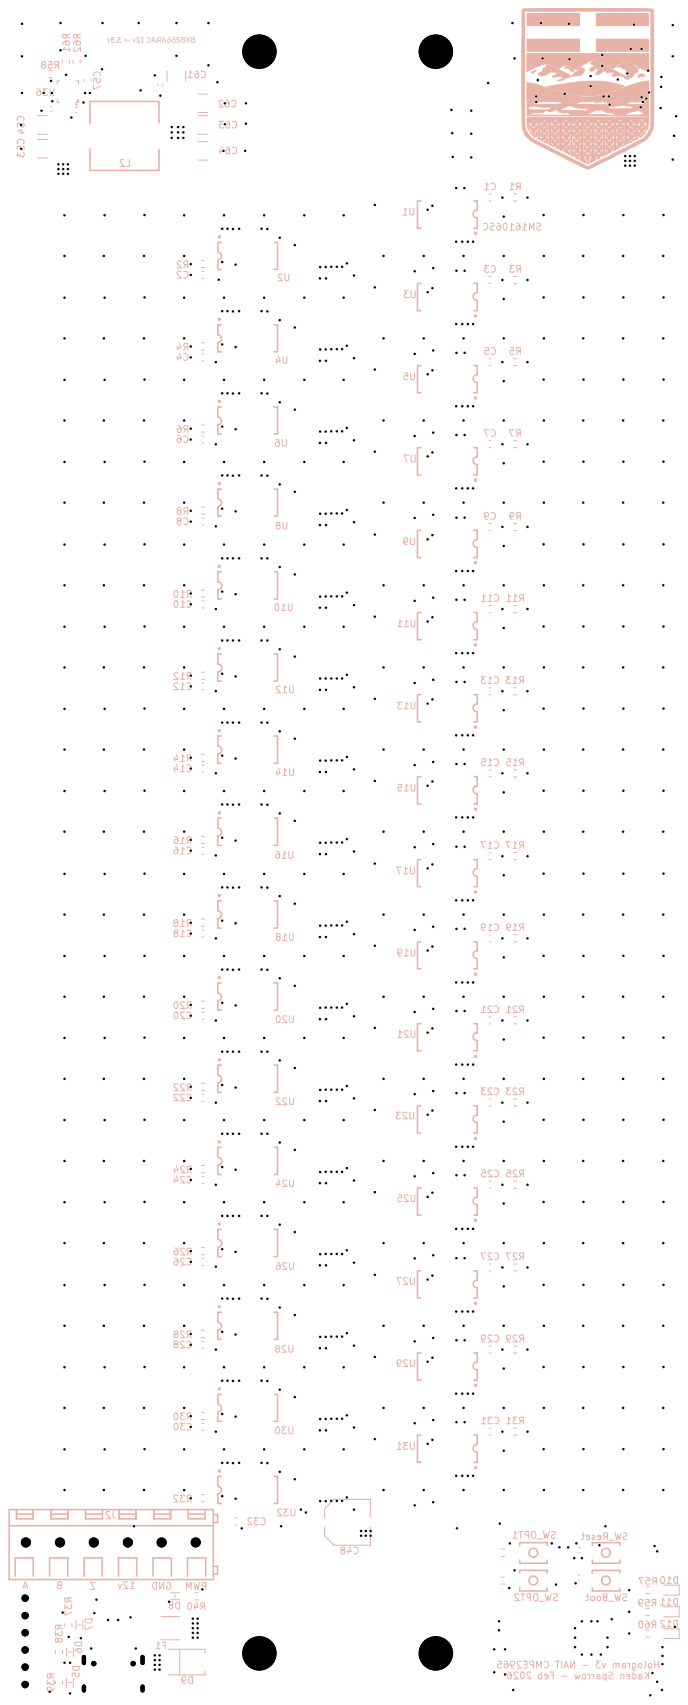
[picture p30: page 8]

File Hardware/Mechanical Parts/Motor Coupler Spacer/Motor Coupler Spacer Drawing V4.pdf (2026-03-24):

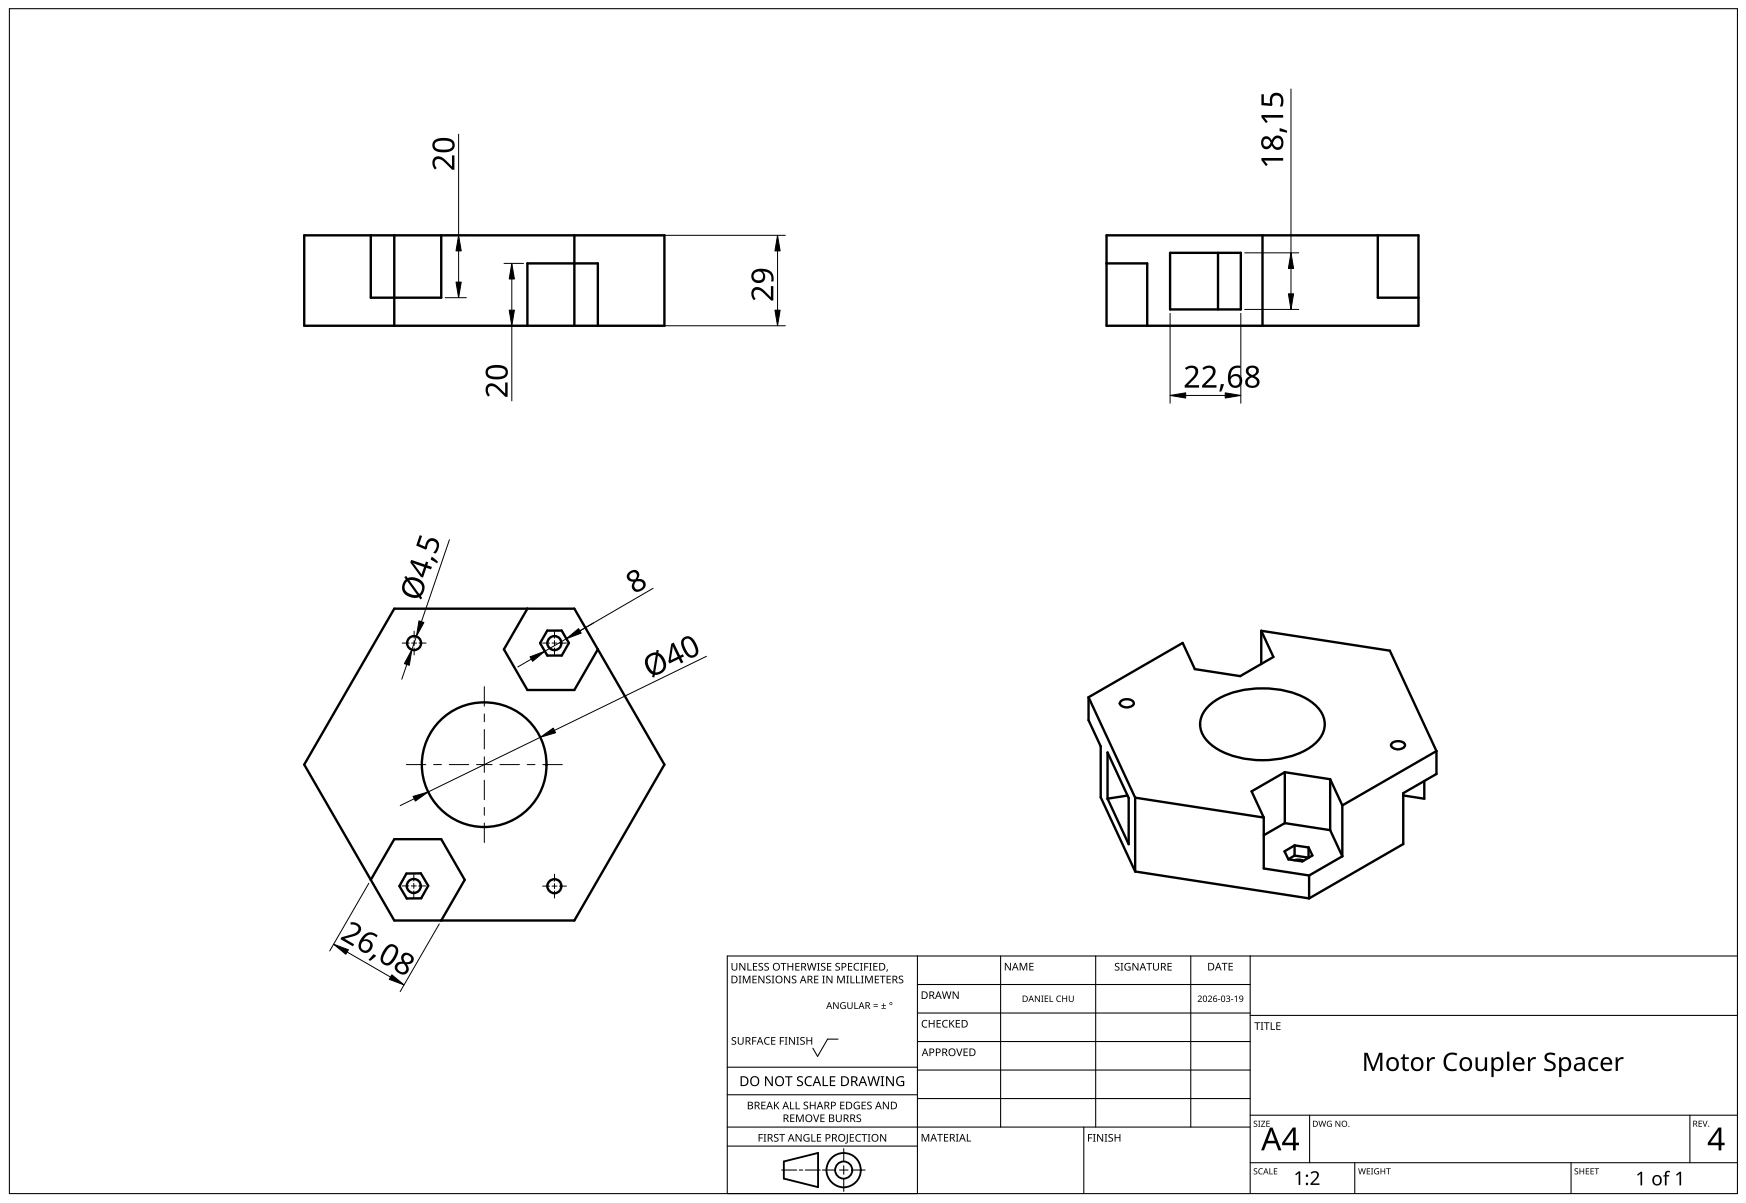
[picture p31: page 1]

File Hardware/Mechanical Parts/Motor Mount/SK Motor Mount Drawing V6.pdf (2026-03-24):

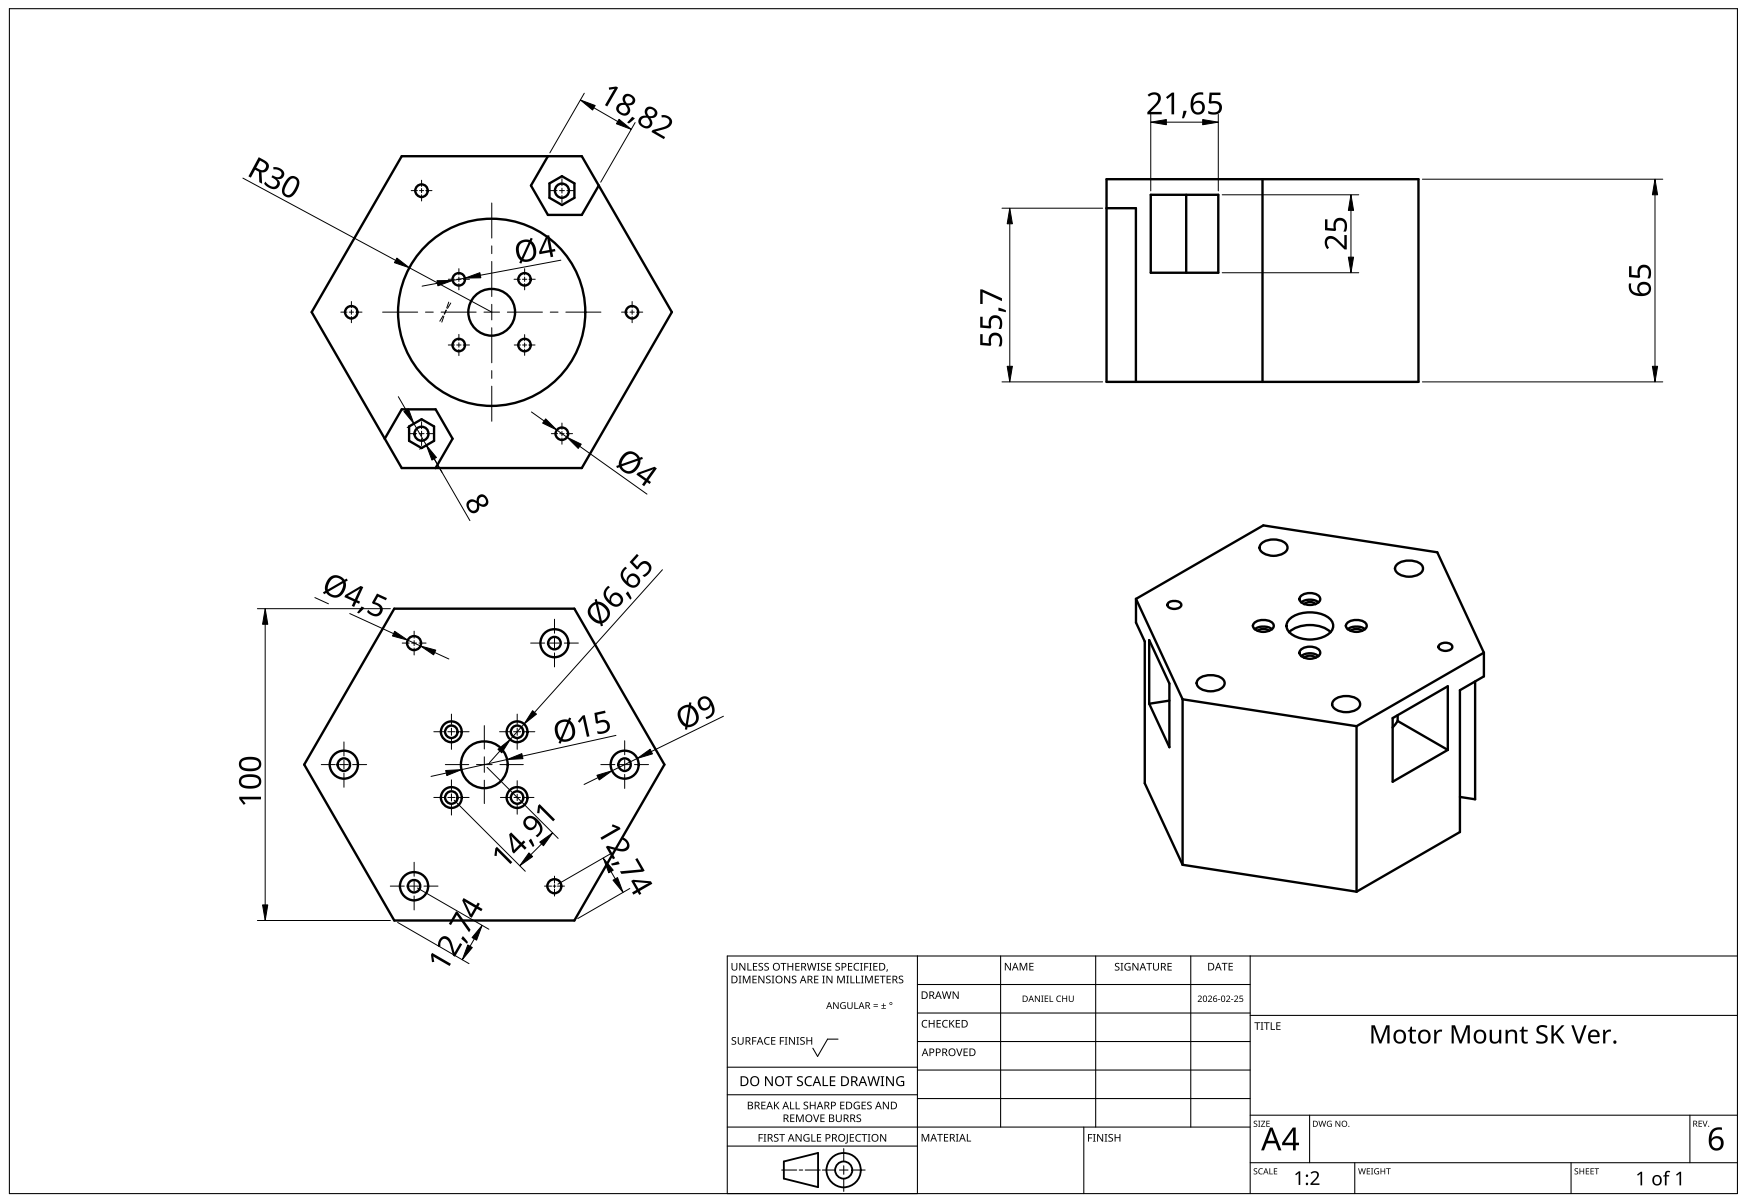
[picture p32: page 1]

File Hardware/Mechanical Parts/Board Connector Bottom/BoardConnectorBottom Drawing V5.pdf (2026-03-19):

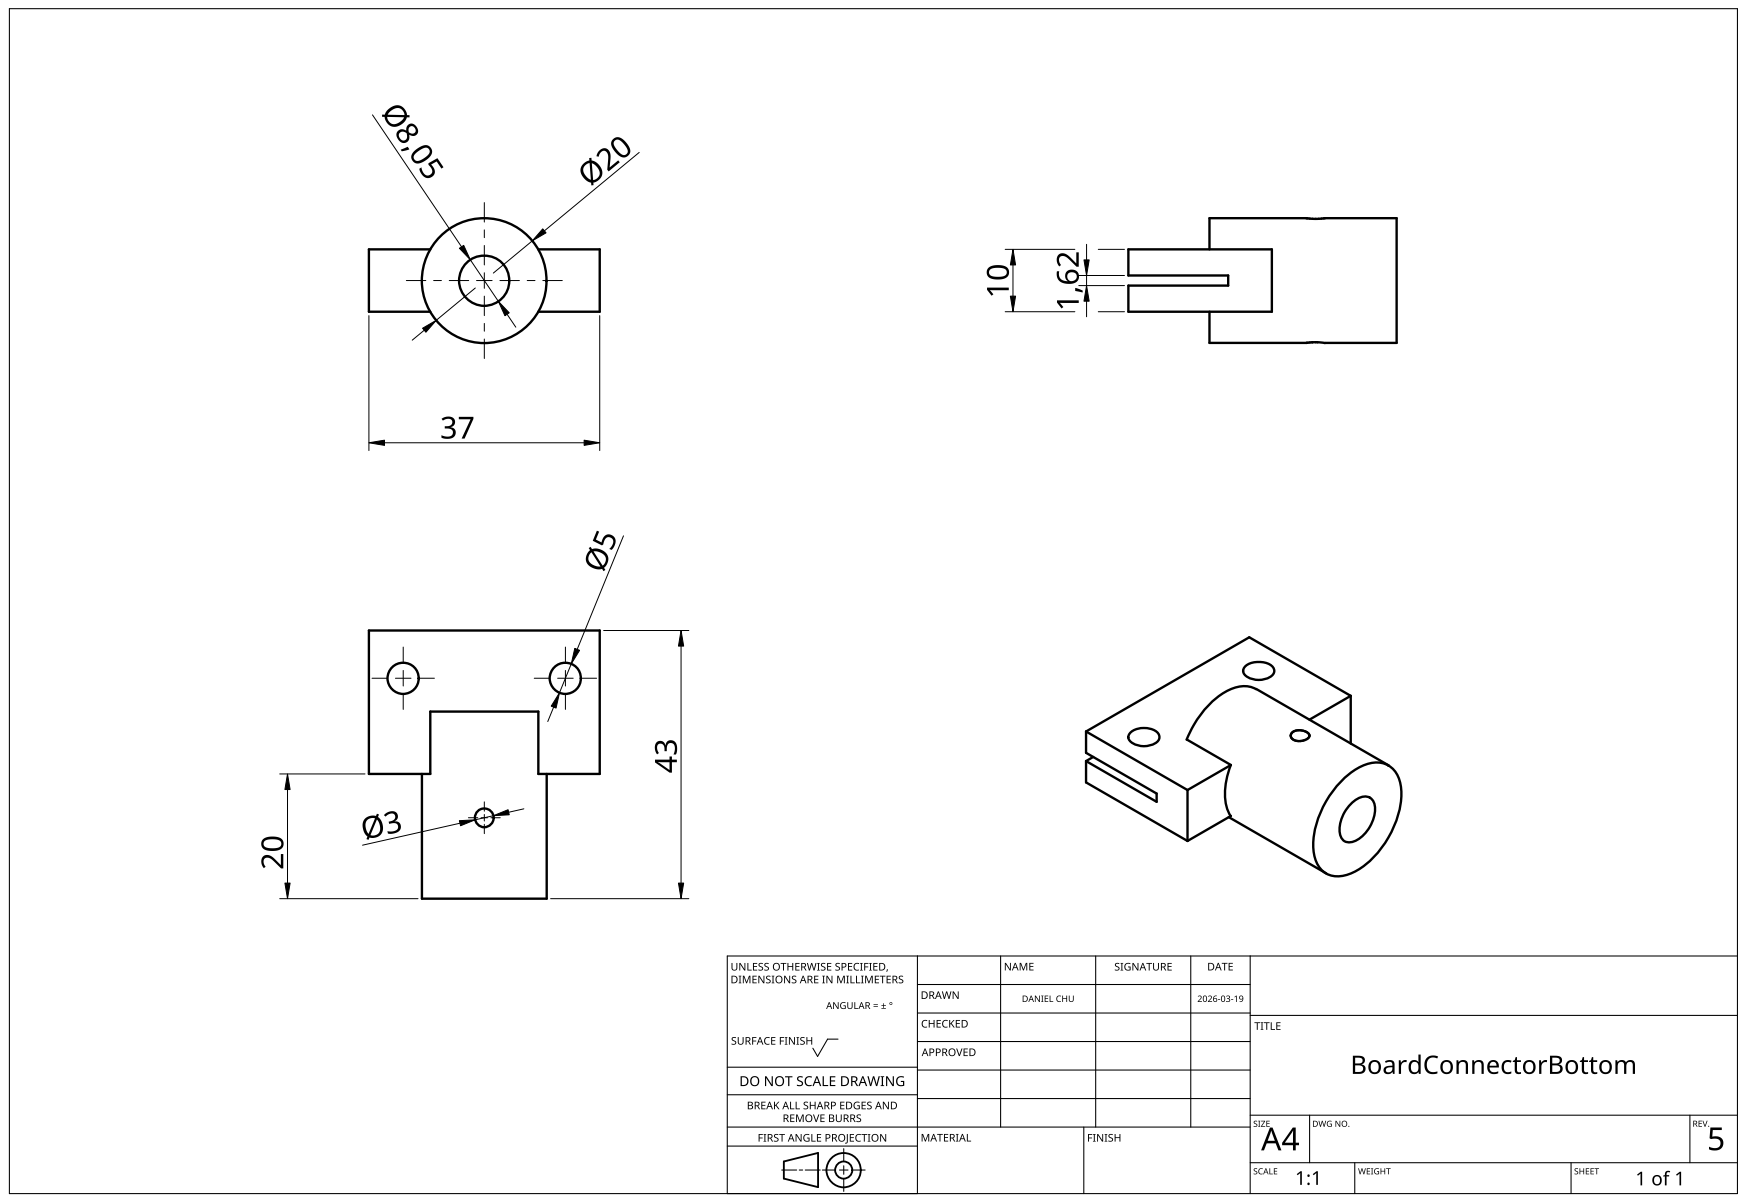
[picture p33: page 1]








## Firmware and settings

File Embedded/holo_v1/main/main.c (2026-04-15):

#include <string.h>
#include "freertos/FreeRTOS.h"
#include "freertos/task.h"
#include "driver/spi_master.h"
#include "driver/gpio.h"
#include "esp_log.h"
#include "esp_err.h"
#include "esp_check.h"
#include "esp_heap_caps.h"
#include "esp_rom_sys.h"   // esp_rom_delay_us()
#include "encoder.h"
#include "buck_4v.h"
#include "shiftreg.h"
#include "shiftreg_pwm.h"
#include "pwm.h"
#include "console_io.h"
#include "display_store.h"
#include "display_task.h"
#include "speed_telemetry.h"
#include "main.h"
#include "wifi_rx.h"


static const char *TAG_main = "main_test";
// -----------------------
// app_main: init and start the test task
// -----------------------
void app_main(void)
{
    esp_err_t err;

	vTaskDelay(pdMS_TO_TICKS(1000));

    //ESP_LOGI(TAG_main, "Shift-register SPI test starting...");

	//config shiftreg
	shiftreg_config.init				= 1;
	shiftreg_config.spi_host 			= SR_SPI_HOST;
	shiftreg_config.pin_mosi 			= PIN_SPI_MOSI;
	shiftreg_config.pin_sclk 			= PIN_SPI_SCLK;
	shiftreg_config.pin_miso 			= PIN_SPI_MISO;
	shiftreg_config.pin_le 				= PIN_SR_LE;
	shiftreg_config.pin_oe 				= PIN_SR_NOT_OE;
	shiftreg_config.spi_clock_hz 		= SR_SPI_HZ;
	shiftreg_config.max_transfer_bytes 	= SR_FRAME_BYTES;

    // config shift-register global brightness PWM
    shiftreg_pwm_config.init                       = 1;
    shiftreg_pwm_config.gpio_num                   = PIN_SR_NOT_OE;
    shiftreg_pwm_config.channel                    = LEDC_CHANNEL_1;
    shiftreg_pwm_config.timer                      = LEDC_TIMER_1;
    shiftreg_pwm_config.frequency_hz               = SR_PWM_HZ;
    shiftreg_pwm_config.startup_brightness_percent = SR_PWM_STARTUP_BRIGHTNESS_PERCENT;
	
	//config pwm
	pwm_config.init			   	= 1;
	pwm_config.gpio_num        	= PIN_ESC_PWM;
	pwm_config.channel         	= LEDC_CHANNEL_0;
	pwm_config.timer           	= LEDC_TIMER_0;
	pwm_config.arm_pulse_us    	= PWM_ESC_ARM_US;
	pwm_config.arm_time_ms     	= PWM_ESC_ARM_TIME_MS;
	pwm_config.command_min_us  	= PWM_ESC_MIN_US;
	pwm_config.command_max_us  	= PWM_ESC_MAX_US;
    
	//config encoder
	encoder_config.init 		= 1;
	encoder_config.pin_a  		= PIN_ENC_A;
	encoder_config.pin_b		= PIN_ENC_B;
	encoder_config.pin_z		= PIN_ENC_Z;
	encoder_config.ab_pull 		= GPIO_FLOATING;
	encoder_config.z_pull		= GPIO_FLOATING;
	encoder_config.glitch_filter_ns = 1000;

	// Configure Wi-Fi receiver in SoftAP mode for packet-header bring-up.
	//
	// Test model:
	// - ESP32 creates its own Wi-Fi network
	// - PC joins that network
	// - PC opens a TCP connection to the ESP32
	// - ESP32 prints each received packet header to the console
	wifi_rx_config.init					= 1;
	strcpy(wifi_rx_config.wifi_ssid, "holo_v1_test");
	strcpy(wifi_rx_config.wifi_password, "holo1234");
	wifi_rx_config.tcp_port			= 3333;
	wifi_rx_config.listen_backlog	= 1;
	wifi_rx_config.max_connections	= 1;
	wifi_rx_config.task_stack_size	= 4096;
	wifi_rx_config.task_priority	= 6;
	wifi_rx_config.print_headers_to_console = true;


    err = shiftreg_init(); 
    if (err != ESP_OK) {
        ESP_LOGE(TAG_main, "shiftreg_init failed: %s", esp_err_to_name(err));
        buck_4v_disable();
        return;
    }

    err = buck_4v_enable_and_wait();
    if (err != ESP_OK) {
        ESP_LOGE(TAG_main, "buck_4v_enable_and_wait failed: %s", esp_err_to_name(err));
        return;
    }

    err = shiftreg_pwm_init();
    if (err != ESP_OK) {
        ESP_LOGE(TAG_main, "shiftreg_pwm_init failed: %s", esp_err_to_name(err));
        buck_4v_disable();
        return;
    }

    err = pwm_init();
    if (err != ESP_OK) {
        ESP_LOGE(TAG_main, "pwm_init failed: %s", esp_err_to_name(err));
        return;
    }

    // err = console_io_init();
    // if (err != ESP_OK) {
    //     ESP_LOGE(TAG_main, "console_io_init failed: %s", esp_err_to_name(err));
    //     return;
    // }

    err = encoder_init();
    if (err != ESP_OK) {
        ESP_LOGE(TAG_main, "encoder_init failed: %s", esp_err_to_name(err));
        return;
    }

    err = display_store_manager_init();
    if (err != ESP_OK) {
        ESP_LOGE(TAG_main, "display_store_manager_init failed: %s", esp_err_to_name(err));
        return;
    }

    err = speed_telemetry_init();
    if (err != ESP_OK) {
        ESP_LOGE(TAG_main, "speed_telemetry_init failed: %s", esp_err_to_name(err));
        return;
    }

    // Start the Wi-Fi receive path after console I/O is ready so received
    // headers can be printed immediately during bring-up testing.
    err = wifi_rx_init();
    if (err != ESP_OK) {
        ESP_LOGE(TAG_main, "wifi_rx_init failed: %s", esp_err_to_name(err));
        return;
    }

    err = wifi_rx_start();
    if (err != ESP_OK) {
        ESP_LOGE(TAG_main, "wifi_rx_start failed: %s", esp_err_to_name(err));
        return;
    }

    ESP_LOGI(TAG_main, "Wi-Fi test AP ready");
    ESP_LOGI(TAG_main, "SSID: %s", wifi_rx_config.wifi_ssid);
    ESP_LOGI(TAG_main, "Password: %s", wifi_rx_config.wifi_password);
    ESP_LOGI(TAG_main, "TCP port: %u", (unsigned)wifi_rx_config.tcp_port);

    // Start the example display task after all hardware drivers are ready.
    err = display_task_start();
    if (err != ESP_OK) {
        ESP_LOGE(TAG_main, "display_task_start failed: %s", esp_err_to_name(err));
    }
}

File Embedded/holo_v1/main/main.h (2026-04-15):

#ifndef MAIN_H
#define MAIN_H

#ifdef __cplusplus
extern "C" {
#endif

// -----------------------
// USER SETTINGS (edit these)
// -----------------------

// SPI pins (set these to whatever pins you wired to the shift-register chain)
#define PIN_SPI_MOSI    	39
#define PIN_SPI_SCLK    	40
#define PIN_SPI_MISO    	-1   // not used

// Shift-register control pins
#define PIN_SR_LE      		41   // latch enable (LE)
#define PIN_SR_NOT_OE      	42   // output enable (OE) - active LOW; set -1 if not connected

//led power
#define PIN_BUCK_4V_EN		9	//pull up to enable 4v buck converter
#define PIN_BUCK_4V_PG		10 	//goes high to signal buck converter is ready for use

//encoder pins
#define PIN_ENC_A			4
#define PIN_ENC_B			5
#define PIN_ENC_Z			6
#define ENC_PPR             2000

// Encoder count mode used by encoder.c.
//
// The current PCNT setup counts both edges of channel A only, which gives x2
// counting relative to the encoder's base pulses-per-revolution spec.
#define ENC_COUNT_MULTIPLIER 2
#define ENC_COUNTS_PER_REV   (ENC_PPR * ENC_COUNT_MULTIPLIER)


//pwm
#define PIN_ESC_PWM			17

// Optional debug pins 
#define PIN_SW_OPT1         21    // set -1 if not used
#define PIN_SW_OPT2			14
#define PIN_LED_RED			11
#define PIN_LED_YELLOW		12
#define PIN_LED_BLUE		13

// SPI host selection (ESP32-S3 typically uses SPI2_HOST or SPI3_HOST)
#define SR_SPI_HOST     SPI2_HOST

// SPI clock rate (start lower for clean waveforms; increase later)
#define SR_SPI_HZ       (8 * 1000 * 1000)  // 8 MHz

// Global display brightness PWM settings on OE.
#define SR_PWM_HZ       (20 * 1000)        // 20 kHz global dimming PWM
#define SR_PWM_STARTUP_BRIGHTNESS_PERCENT 10U

// Display strobe settings.
//
// Each slice can be shown for only a fraction of its angular interval by
// gating the OE PWM output. The hybrid pulse width is recomputed once per
// revolution from the measured revolution period and active step count, then
// clamped between the bounds below.
#define DISPLAY_STROBE_ENABLED       1
#define DISPLAY_STROBE_DUTY_PERCENT  8U
#define DISPLAY_STROBE_MIN_ON_US     40U
#define DISPLAY_STROBE_MAX_ON_US     120U

// Our frame is 512 LEDs -> 512 bits -> 64 bytes
#define SR_FRAME_BYTES  64
#define DISPLAY_SLICE_BYTES SR_FRAME_BYTES

// How often to send the frame in this test (later this will be encoder-triggered)
#define TEST_SEND_PERIOD_MS  1000

#ifdef __cplusplus
}
#endif

#endif // MAIN_H

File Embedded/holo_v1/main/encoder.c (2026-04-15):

#include "encoder.h"

#include <stddef.h>

#include "driver/pulse_cnt.h"
#include "esp_log.h"
#include "esp_check.h"
#include "esp_heap_caps.h"

static const char *TAG_encoder = "encoder";

// Saved configuration
encoder_config_t encoder_config = {
	.init = -1,
    .pin_a = -1,                  // Encoder A channel
    .pin_b = -1,                 // Encoder B channel
    .pin_z = -1,                  // Encoder Z / index channel, or -1 if not used

    .ab_pull = -1,   // Pull mode for A/B pins
    .z_pull = -1,    // Pull mode for Z pin

    .glitch_filter_ns = -1  // PCNT glitch filter length in ns
};

// PCNT handles
static pcnt_unit_handle_t g_pcnt_unit = NULL;
static pcnt_channel_handle_t g_pcnt_chan = NULL;

// Optional task to notify when Z occurs
static TaskHandle_t z_notify_task = NULL;
static TaskHandle_t count_notify_task = NULL;

// Counts how many Z pulses have occurred
static volatile uint32_t z_rev_count = 0;
// Most recent watch point seen by the PCNT ISR.
//
// This simpler implementation keeps only the latest fired threshold. If
// several watch points fire before the task handles the notification, newer
// values overwrite older ones.
static volatile int last_watch_point = 0;
// Values currently loaded into the PCNT watch-point hardware.
//
// The PCNT peripheral owns the actual thresholds. This array only tracks which
// ones the firmware added so they can be removed and replaced later.
static int *loaded_watch_points = NULL;
static size_t loaded_watch_point_count = 0;
static size_t loaded_watch_point_capacity = 0;

// Tracks whether the module has been initialized
static bool encoder_initialized = false;

// Ensure there is enough RAM to remember all active watch points.
static esp_err_t encoder_reserve_watch_point_capacity(size_t required_capacity)
{
    int *resized_watch_points;
    size_t new_capacity;

    if (required_capacity <= loaded_watch_point_capacity) {
        return ESP_OK;
    }

    new_capacity = loaded_watch_point_capacity;
    if (new_capacity == 0U) {
        new_capacity = 8U;
    }

    while (new_capacity < required_capacity) {
        new_capacity *= 2U;
    }

    resized_watch_points = (int *)heap_caps_realloc(
        loaded_watch_points,
        new_capacity * sizeof(*loaded_watch_points),
        MALLOC_CAP_8BIT
    );
    if (resized_watch_points == NULL) {
        return ESP_ERR_NO_MEM;
    }

    loaded_watch_points = resized_watch_points;
    loaded_watch_point_capacity = new_capacity;

    return ESP_OK;
}

// --------------------------------------------------
// Small helper: configure an input pin
// --------------------------------------------------

esp_err_t encoder_config_input_pin(int pin, gpio_pull_mode_t pull_mode, gpio_int_type_t intr_type)
{
    if (pin < 0) {
        return ESP_OK;
    }

    gpio_config_t cfg = {
        .pin_bit_mask = (1ULL << pin),
        .mode = GPIO_MODE_INPUT,
        .pull_up_en = (pull_mode == GPIO_PULLUP_ONLY) ? GPIO_PULLUP_ENABLE : GPIO_PULLUP_DISABLE,
        .pull_down_en = (pull_mode == GPIO_PULLDOWN_ONLY) ? GPIO_PULLDOWN_ENABLE : GPIO_PULLDOWN_DISABLE,
        .intr_type = intr_type
    };

    return gpio_config(&cfg);
}

// --------------------------------------------------
// Z index interrupt handler
//
// Keep this very short.
// We only:
// 1) increment revolution counter
// 2) optionally notify a task
// --------------------------------------------------

void encoder_z_isr(void *arg)
{
    (void)arg;

    z_rev_count++;

    BaseType_t higher_prio_woken = pdFALSE;

    if (z_notify_task != NULL) {
        xTaskNotifyFromISR(
            z_notify_task,
            ENCODER_NOTIFY_EVENT_Z,
            eSetBits,
            &higher_prio_woken
        );
    }

    if (higher_prio_woken) {
        portYIELD_FROM_ISR();
    }
}

static bool encoder_pcnt_on_reach(pcnt_unit_handle_t unit, const pcnt_watch_event_data_t *edata, void *user_ctx)
{
    BaseType_t higher_prio_woken = pdFALSE;

    (void)unit;
    (void)user_ctx;

    last_watch_point = edata->watch_point_value;

    if (count_notify_task != NULL) {
        xTaskNotifyFromISR(
            count_notify_task,
            ENCODER_NOTIFY_EVENT_COUNT,
            eSetBits,
            &higher_prio_woken
        );
    }

    return (higher_prio_woken == pdTRUE);
}

// --------------------------------------------------
// Initialize PCNT for quadrature-style counting
//
// Simple method:
// - A is the pulse input
// - B is the direction control input
// - count the rising edge of A
// --------------------------------------------------

esp_err_t encoder_init_pcnt(void)
{
    const pcnt_event_callbacks_t cbs = {
        .on_reach = encoder_pcnt_on_reach,
    };

    // Create PCNT unit
    pcnt_unit_config_t unit_cfg = {
        .high_limit = 32767,
        .low_limit  = -32768,
    };

    ESP_RETURN_ON_ERROR(pcnt_new_unit(&unit_cfg, &g_pcnt_unit), TAG_encoder, "pcnt_new_unit failed");

    // Optional glitch filter to reject short noise spikes
    if (encoder_config.glitch_filter_ns > 0) {
        pcnt_glitch_filter_config_t filter_cfg = {
            .max_glitch_ns = encoder_config.glitch_filter_ns,
        };

        ESP_RETURN_ON_ERROR(
            pcnt_unit_set_glitch_filter(g_pcnt_unit, &filter_cfg),
            TAG_encoder,
            "pcnt_unit_set_glitch_filter failed"
        );
    }

    // A = edge input, B = level input
    pcnt_chan_config_t chan_cfg = {
        .edge_gpio_num  = encoder_config.pin_a,
        .level_gpio_num = encoder_config.pin_b,
    };

    ESP_RETURN_ON_ERROR(
        pcnt_new_channel(g_pcnt_unit, &chan_cfg, &g_pcnt_chan),
        TAG_encoder,
        "pcnt_new_channel failed"
    );

    // Count only the rising edge of A.
    //
    // If x2 counting is needed later, change the falling-edge action from
    // HOLD to INCREASE and update ENC_COUNT_MULTIPLIER to match.
    ESP_RETURN_ON_ERROR(
        pcnt_channel_set_edge_action(
            g_pcnt_chan,
            PCNT_CHANNEL_EDGE_ACTION_INCREASE,   // rising edge of A
            PCNT_CHANNEL_EDGE_ACTION_INCREASE        // falling edge of A
        ),
        TAG_encoder,
        "pcnt_channel_set_edge_action failed"
    );

    // Use B to control direction
    //
    // If the direction is backwards on your hardware,
    // swap KEEP and INVERSE here.
    ESP_RETURN_ON_ERROR(
        pcnt_channel_set_level_action(
            g_pcnt_chan,
            PCNT_CHANNEL_LEVEL_ACTION_KEEP,      // B high
            PCNT_CHANNEL_LEVEL_ACTION_KEEP    // B low
        ),
        TAG_encoder,
        "pcnt_channel_set_level_action failed"
    );

    ESP_RETURN_ON_ERROR(
        pcnt_unit_register_event_callbacks(g_pcnt_unit, &cbs, NULL),
        TAG_encoder,
        "pcnt_unit_register_event_callbacks failed"
    );
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

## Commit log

2026-01-29 created kicad gitignore
2026-01-29 added kicad projects for pcb blade
    [testhologram v2-B_Cu.gbr, testhologram v2-B_Mask.gbr, testhologram v2-B_Paste.gbr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]
2026-02-03 tinkered with some test code for esp32
2026-02-03 added esp32 devboard docs into dataheets folder, updated hologram kicad schematic
    [testhologram v2.kicad_sch]
2026-02-04 worked on kicad
    [testhologram v2.kicad_sch]
2026-02-05 added parts to schematic. added footprints/models
    [testhologram v2.kicad_sch]
2026-02-09 i did some kicad stuff
    [testhologram v2.kicad_sch]
2026-02-09 added new buck converter
    [testhologram v2.kicad_sch]
2026-02-09 allow 3d files in hardware folder
    [Slip Ring Connector V1.stl]
2026-02-09 slip ring connector V2
    [Slip Ring Connector V1.stl, Slip Ring Connector V2.stl]
2026-02-09 motor mount V1
    [Motor connector V1.stl]
2026-02-10 added buck converters for 12v->4v and 12v->3.3v. added footprints
    [testhologram v2.kicad_sch]
2026-02-10 added debug leds and debug buttons
    [testhologram v2.kicad_sch]
2026-02-10 adding footprints
    [testhologram v2.kicad_sch]
2026-02-11 finished schematic, working on pcb design
    [testhologram v2.kicad_sch]
2026-02-11 Changed mounting holes to match motor
    [Motor connector V2.stl]
2026-02-11 added m3 slip ring mounting holes
    [Slip Ring Connector V4.stl]
2026-02-11 made new revision of kicad folder.
    [hologram v3-B_Cu.gbr, hologram v3-B_Mask.gbr, hologram v3-B_Paste.gbr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]
2026-02-11 added test shaft bolt adapter
    [Test Shaft Bolt Adapter.stl]
2026-02-11 added mounting pegs for testing rotor
    [Motor connector V3.stl, Slip Ring Connector V4.stl]
2026-02-12 kicad placed all parts, just need to wire 3.3v buck then review design
    [hologram v3.kicad_sch]
2026-02-12 kicad routed le, oe, clk, mosi, addded debug header pins
    [hologram v3.kicad_sch]
2026-02-13 wired in the debug pins
    [hologram v3.kicad_sch]
2026-02-18 hologram done and submitted for printing
    [hologram v3-B_Cu.gbr, hologram v3-B_Mask.gbr, hologram v3-B_Paste.gbr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]
2026-02-26 added SK motor mount V1
    [SK Motor Mount V1.stl]
2026-02-26 added slip ring connector V6
    [Slip Ring Connector V6.stl]
2026-02-26 added V2 of motor mount
    [SK Motor Mount V2.stl]
2026-02-26 added test slip ring shaft adapter
    [Slip Ring Shaft Adapter.stl]
2026-03-03 updated Sk motor mount
    [SK Morot Mount V3.stl]
2026-03-03 pwm testing
2026-03-05 added code totest spi
2026-03-05 added rotary encoder mount
    [Rotary Encoder Mount V1.stl]
2026-03-19 added close to final versions of 3d Printed mechanical parts
    [BoardConnectorBallancer.stl, BoardConnectorBottom V5.stl, BoardConnectorTop V2.stl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]
2026-03-22 board ballancer pinhole size too small to print... trying a larger size
    [BoardConnectorBallancer V2.stl]
2026-03-24 Mechanical parts new Mounting accesss window
    [Motor Coupler Spacer V4.stl, SK Motor Mount V6.stl]
2026-03-24 laptop is not fried yay. pwm test is done and working
2026-03-24 pwm test added functionality to use console on the usb-otg usbheader and cleaned up main.c
2026-03-25 updated hologram kicad to have all part nums and datasheet links. added screenshots of scematics for report
    [hologram v3.kicad_sch]
2026-03-25 added console io and pwm to holov1
2026-03-26 cropped schematic
2026-03-31 removed leftover PDB traces
2026-03-31 pwm updates
2026-04-03 added structs for receiving frame data from server
2026-04-05 update wifi header, payload send to esp32 from UI now works
2026-04-07 embedde code, the encoder now triggers slice updates at desired locations during rotation
2026-04-09 pcb go blinky mode
2026-04-09 added more juice to the spi clk line
2026-04-10 added send obj button
2026-04-12 removing consoleio, pwm brightness, new wave demoframe, fixed testui img loading dropdown
    [display_task.c, main.c, main.h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]
2026-04-13 motor is now controllable from wifi via pulse width
2026-04-13 speed control with duplicate frames to converter
2026-04-14 removed setting rpm speed in constructor. plz dont set rpm anywhere except rpm update button. for saftey.
2026-04-15 removed old debug button
2026-04-15 fixed arcing of leds
    [display_task.c, main.h]
